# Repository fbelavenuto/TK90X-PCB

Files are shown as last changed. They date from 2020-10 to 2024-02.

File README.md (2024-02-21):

# TK90X-PCB

Recriação da placa de circuito impresso do microcomputador de 8 bits TK90X da Microdigital. Projeto iniciado em setembro de 2020.

## Agradecimentos

Agradecimentos ao Daniel Viana (Danjovic) pelo desenho do esquema no software Eagle, Manoel Carvalho (Neco) pelo encorajamento e scans limpos da PCB e ao grupo [Clube do TK](https://www.facebook.com/groups/clubedotk) do Facebook.

## Revisões

Nesse repositório existem várias revisões relacionadas abaixo, cada revisão contém modificações em relação à revisão anterior.

### Rev. 3

Réplica da placa Rev. 3 da Microdigital (Silk TK90X-B rev 3). Essa versão é para montagem de uma réplica da placa original, sem modificações.

### Rev. 4

As modificações efetuadas são:
- Jumpers de solda para selecionar o tipo de memória DRAM, roteando a alimentação corretamente,
- Jumper de solda para permitir o uso de uma EPROM no lugar da ROM original.

### Rev. 5

As modificações efetuadas são:
- Jumpers de solda nos conectores EAR e MIC para opção de montagem com Jacks P2 mono ou estéreo e saída de áudio no conector MIC
-  Desativação do circuito de RF dando lugar a uma saída de vídeo-composto on-board e conector RCA próprio.

Essa revisão não é encorajada a ser fabricada.

### Rev. 6

As modificações efetuadas são:
- Alteração no IC10 para corrigir a leitura da porta 254, compatibilizando esta porta com o padrão ZX e permitindo a execução de mais softwares.

Alguns componentes não precisam ser montados pela extinção do circuito de RF, veja a documentação específica na pasta *Docs* da revisão.

### Rev. 7

As modificações efetuadas são:
- Alteração nos componentes do circuito de vídeo:
  - Retirados os componentes não necessários referente ao circuito de RF,
  - IC12 foi rotacionado para abrir espaço para um conector RCA extra.
- Adicionado conectores dupont/pinheader:
  - Botão de RESET externo,
  - Chave para seleção de frequência vertical da ULA,
  - LED para uso no gabinete do TK95.
- Jumper de solda para seleção do tipo de sinal de vídeo a ser codificado (NTSC ou PAL/PAL-M) de acordo com o valor de cristal escolhido.
- Jumper de solda para permitir a ligação do sinal necessário para uso da interface [TK-MEM 128K](http://www.luccas.com.br/index.php/8-bits/artigos/23-preparando-o-tk90x-tk95-para-a-tkmem-128).

O conector RCA extra está posicionado no mesmo lugar da saída de RF do ZX Spectrum original, permitindo a montagem da placa dentro do seu gabinete original. Este conector extra é configurado por um jumper de solda que permite mapear o sinal de vídeo ou o sinal de áudio dando a opção de colocar um segundo RCA adaptando o case de um TK90X e ter saída de áudio em RCA.

# Pastas

*Common* possui arquivos referentes a todas as revisões.

Dentro de cada pasta de cada revisão há três subpastas com os nomes *Docs*, *Eagle* e *Gerber*. O esquema elétrico em PDF, imagens, lista de materiais, etc, estão em *Docs*. Na subpasta *Eagle* há os arquivos originais para a versão 9 do software Autodesk Eagle. Para a confecção das placas há os arquivos em formato gerber na pasta *Gerber* que podem ser enviados para uma empresa de fabricação de PCBs.

Para a Rev.7 abra o arquivo [ibom.html](Rev7/Docs/ibom.html) localmente ou acesse [este link](https://fbelavenuto.github.io/pages/TK90X-PCB-Rev7-ibom.html) para visualizar os componentes e seus lugares na placa. Criado com o projeto [InteractiveHtmlBom](https://github.com/openscopeproject/InteractiveHtmlBom), linha de comando: `generate_interactive_bom --highlight-pin1 all --blacklist-empty-val TK90X.brd`

# Observações

É encorajado a fabricação da Rev. 7 por conter mais opções de configuração e correções de problemas conhecidos.

É recomendado a fabricação com finalização ENIG ou ouro no conector Edge para mais durabilidade.

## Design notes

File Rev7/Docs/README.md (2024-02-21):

# Placa TK90X/95 revisão 7

## Lista de materiais

Os componentes estão relacionados [neste](Lista_Material.md) arquivo.

## Instruções de montagem

Algums componentes são opcionais, explicado no texto. A lista de materiais não contempla chaves e botões opcionais relatados no texto.

Para facilitar a montagem abra o arquivo [ibom.html](Rev1/Docs/ibom.html) localmente ou acesse [este link](https://fbelavenuto.github.io/pages/TK90X-PCB-Rev7-ibom.html) para visualizar os componentes e seus lugares na placa. Existe também o arquivo PDF [mapa.pdf](mapa.pdf) para impressão.

Começe soldando os componentes que são montados deitados, como alguns resistores e diodos. Depois solde os componentes que são montados em pé. Deixe os circuitos integrados e conectores para o final.

É possível usar soquetes nos CIs. Para a ULA, caso use a versão clonada em CPLD, utilize soquete torneado para melhor encaixe.

Ao montar a placa, não é necessário soldar nada em `JP`, a PCB já vem com a conexão certa.

Se for utilizar uma EPROM, grave-a com o conteúdo do arquivo [ROM](../../Common/TK90X_ROM_Rev6_7.BIN)

Não esqueça de colocar um dissipador apropriado para o regulador 7805. É possível adaptar uma placa conversora de tensão DC/DC no lugar do 7805.

### Opções de montagem e configuração

No conector de energia `X1` existe o jumper `J1` para configurar o tipo de jack usado. Feche `J1` para jack P2 mono ou deixe aberto para jack P2 estéreo.

Se escolher montar com 32K de RAM alta, montar `IC5`, `IC6`, `IC7`, `IC21`, `IC22`, `IC23`, `IC24`, `IC25`, `IC26`, `IC27` e não montar `D11`, `D12`, `R33`.

Caso escolha somente 16KB de RAM baixa, não montar `IC5`, `IC6`, `IC7`, `IC21`, `IC22`, `IC23`, `IC24`, `IC25`, `IC26`, `IC27` e montar `D11`, `D12`, `R33`.

Nas memórias da RAM baixa, se for utilizar CIs 4116 feche o jumper `J2` para 12V e feche `J3`, se for utilizar CIs 4164 feche o jumper `J2` para 5V e não feche `J3`.

Se for usar a ROM (PROM) original, fechar o jumper `J9` no lado `R`, se for usar EPROM (27C128) fechar jumper no lado `E`.

O jumper `J10` se aberto configura a ULA para trabalhar em 60Hz de sincronismo vertical. Se fechá-lo a ULA é configurada para 50Hz. Pode ser utilizado uma chave externa para esta função.

É possível escolher o padrão de saída de vídeo PAL-M ou NTSC. Para PAL-M utilize um cristal de 14.3044 MHz e feche o jumper `J7` para PAL. NTSC utilize cristal de 14.318MHz e feche `J7` para NTSC.

Na saída e entrada de K7 é possível configurar de acordo com o tipo de conector desejado:
 - No conector do EAR, se utilizar um jack P2 mono, feche o jumper `J5`, se for jack estéreo, feche `J5` somente se for utilizar cabo estéreo. Para jack estéreo e cabo mono não feche `J5`.
 - No conector do MIC utilize um jack estéreo e feche `J4` se quiser saída de áudio no canal esquerdo, ou deixe `J4` aberto para não ter saída de áudio. A saída de som K7 sai pelo canal direito.

A saída de vídeo está ligada no conector RCA `X4`, é possível soldar um conector RCA em `X5` e pelo jumper `J8` escolher que sinal estará presente nesse conector:
 - Se for montar para gabinete ZX não solde `X4`, solde `X5` e configure `J8` para vídeo.
 - Caso queira furar o gabinete do TK90X e ter uma saída de áudio em RCA, solde também `X5` e configure `J8` para áudio.

`X7` é o conector de joystick, solde-o para gabinete TK90X e não o solde para gabinete ZX caso não queira furar o gabinete.

Outra opção de jumper de solda é a conexão para a interface TKMEM. Feche `J6` caso queira ligar o barramento ao circuito responsável por desligar a RAM alta ao conectar a TKMEM.

Caso deseje colocar um push-button externo para RESET, ligue-o ao conector `X8`.

#### Relação de jumpers:

Segue um resumo dos jumpers de solda:

| Nome | Função |
|---|---|
| `JP` | fase de clock |
| `J1` | Jack power mono/estéreo |
| `J2` | Alimentação 12V/5V para as DRAMs |
| `J3` | Alimentação -5V para as DRAMs |
| `J4` | Saída de áudio pelo conector MIC |
| `J5` | Jack EAR mono/estéreo |
| `J6` | Opção TK-MEM |
| `J7` | NTSC/PAL |
| `J8` | Vídeo/áudio em X5 |
| `J9` | ROM/EPROM |
| `J10` | ULA 50/60 Hz |

#### Relação de test points:

Para diagnósticos existem pontos de teste relacionados abaixo:

| Nome | Nome do sinal |
|---|---|
| `TP1` | Clock Z80 |
| `TP2` | Clock ULA |
| `TP3` | Entrada K7 |
| `TP4` | DRAM /RAS |
| `TP5` | DRAM /CAS |
| `TP6` | DRAM /WR |
| `TP7` | Saída Beep ULA |
| `TP8` | Sincronismo composto |
| `TP9` | /ROM select |
| `TP10` | /IRQ |

## Fotos

Segue exemplo de montagem. Foi utilizado soquetes, uma placa DC/DC no lugar do 7805, DRAMs 4416 e EPROM.
 Nesta montagem de validação foram testados todas as opções. Não foi soldado um conector em `X5`, os jacks do MIC e EAR são estéreos e o Jack `X1` é mono. Foi utilizado nos testes uma ULA original e um clone em FPGA, que aparece nas fotos.

Lado dos componentes
*Lado dos componentes*

Lado da solda
*Lado da Solda*

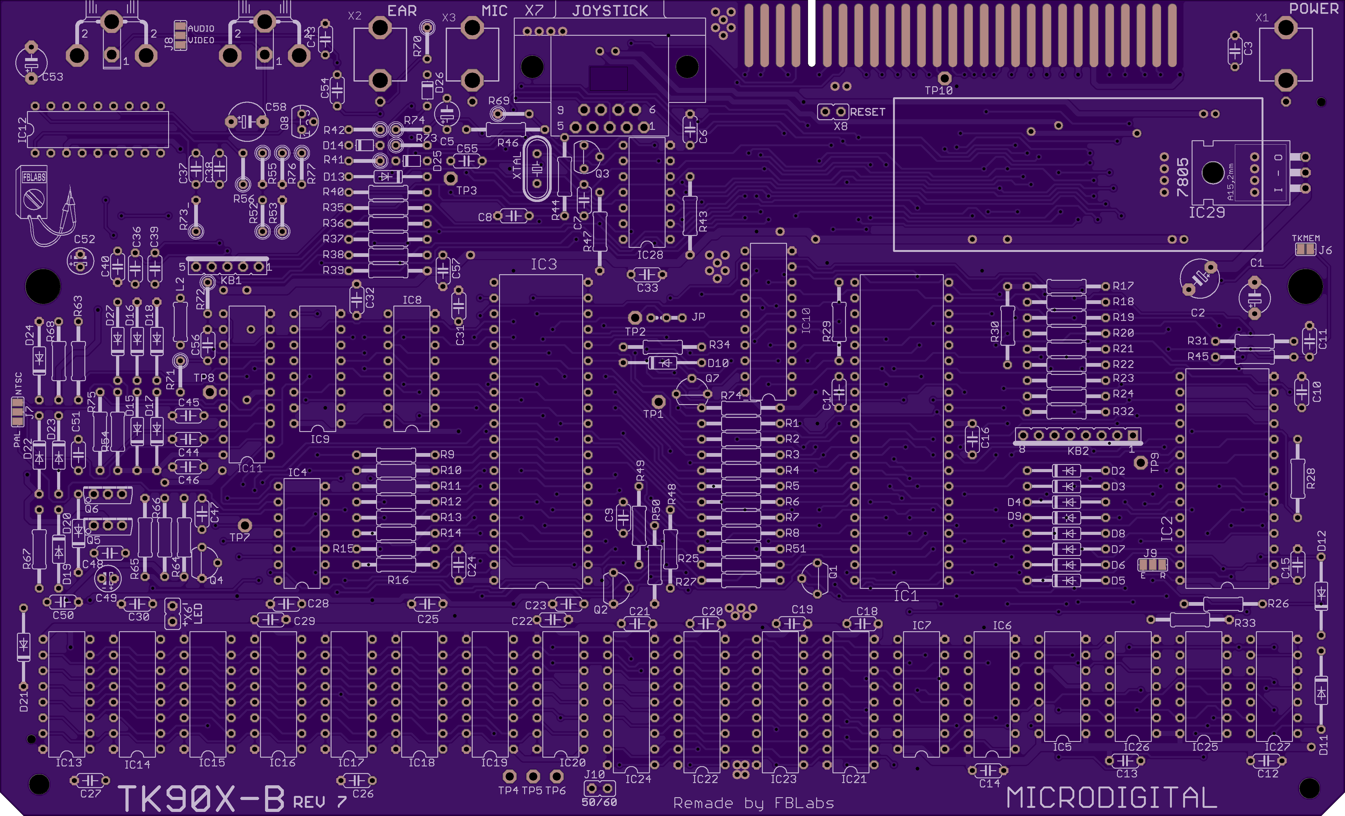
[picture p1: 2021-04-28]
Rev7/Docs/TK90X_PCB_render_top.png

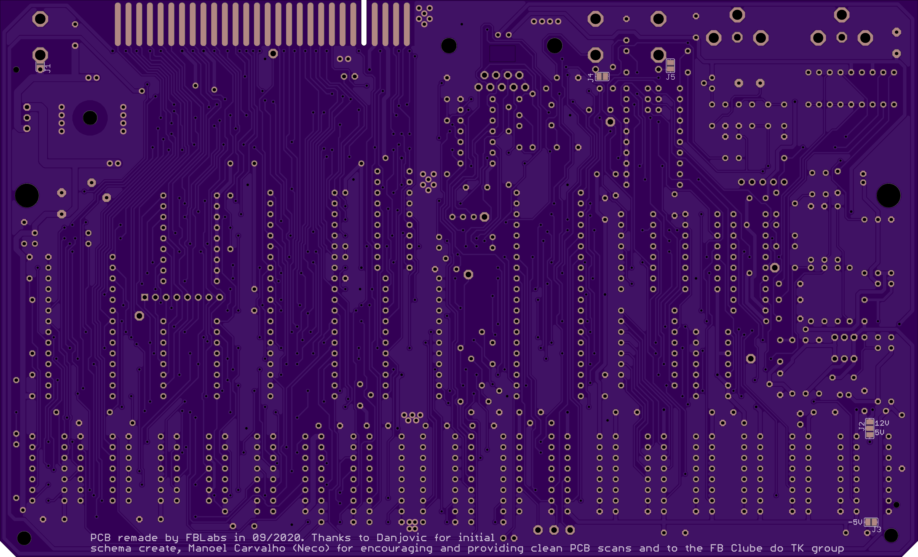
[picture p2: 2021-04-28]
Rev7/Docs/TK90X_PCB_render_bottom.png

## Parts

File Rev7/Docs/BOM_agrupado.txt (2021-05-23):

Qty Value       Device          Package      Parts                                                                                                                                               Description
1   Z80         Z80CPU          DIL40        IC1                                                                                                                                                 Z80 FAMILY DEVICE
1   ROM         25128           DIL28        IC2
1   ULA TK90    ULA-TK90        DIL40        IC3
1   LM1886      LM1886N         DIL20        IC11
1   LM1889      LM1889          DIL18        IC12
8   4116        MK4516          DIL16        IC13, IC14, IC15, IC16, IC17, IC18, IC19, IC20
4   4416        4416            DIL18        IC21, IC22, IC23, IC24                                                                                                                              MEMORY
2   74LS00      74LS00N         DIL14        IC25, IC26                                                                                                                                          Quad 2-input NAND gate
1   74LS04      74LS04N         DIL14        IC28                                                                                                                                                Hex INVERTER
4   74LS157     74S157N         DIL16        IC6, IC7, IC8, IC9                                                                                                                                  Quadruple 2-line to 1-line data SELECTOR/MULTIPLEXER
1   74LS244N    74LS244N        DIL20        IC10                                                                                                                                                Octal BUFFER and LINE DRIVER, 3-state
1   74LS32      74LS32N         DIL14        IC27                                                                                                                                                Quad 2-input OR gate
2   74LS74      74LS74N         DIL14        IC4, IC5                                                                                                                                            Dual D type positive edge triggered FLIP FLOP, preset and clear
1   7805        78XXL           78XXL        IC29                                                                                                                                                VOLTAGE REGULATOR
1   BC517       BC517           TO92         Q8                                                                                                                                                  NPN Darlington Transistor
4   BC548       -NPN-TO92L      TO92L        Q1, Q2, Q4, Q7                                                                                                                                      NPN Transistror
1   BD136       BD140           TO126AV      Q6                                                                                                                                                  PNP TRANSISTOR
1   BD139       BD139           TO126AV      Q5                                                                                                                                                  NPN TRANSISTOR
1   BF494       BF494           TO92-CEB     Q3                                                                                                                                                  NPN TRANSISTOR
21  1N4148      DDO35-12        DO35-12      D2, D3, D4, D5, D6, D7, D8, D9, D10, D11, D12, D13, D15, D16, D17, D18, D19, D20, D22, D23, D27                                                     Diodo
3   1N4148      DIODE-D-5       D-5          D14, D25, D26                                                                                                                                       DIODE
1   5V          DDO35-12        DO35-12      D21                                                                                                                                                 Diodo
1   12V         DDO35-12        DO35-12      D24                                                                                                                                                 Diodo
1   14.3044MHz  CRYSTALHC49S    HC49/S       XTAL                                                                                                                                                CRYSTAL
1   33          R-EU_0207/12    0207/12      R68                                                                                                                                                 RESISTOR, European symbol
1   75          R-EU_0207/5V    0207/5V      R77                                                                                                                                                 RESISTOR, European symbol
1   100         R-EU_0207/12    0207/12      R47                                                                                                                                                 RESISTOR, European symbol
3   100         R-EU_0207/5V    0207/5V      R42, R69, R70                                                                                                                                       RESISTOR, European symbol
1   150         R-EU_0207/5V    0207/5V      R76                                                                                                                                                 RESISTOR, European symbol
2   220         R-EU_0207/12    0207/12      R16, R48                                                                                                                                            RESISTOR, European symbol
23  470         R-EU_0207/12    0207/12      R1, R2, R3, R4, R5, R6, R7, R8, R9, R10, R11, R12, R13, R14, R15, R25, R26, R27, R28, R34, R45, R66, R67                                            RESISTOR, European symbol
1   680         R-EU_0207/5V    0207/5V      R41                                                                                                                                                 RESISTOR, European symbol
4   1K          R-EU_0207/12    0207/12      R33, R49, R50, R65                                                                                                                                  RESISTOR, European symbol
2   1K          R-EU_0207/5V    0207/5V      R55, R56                                                                                                                                            RESISTOR, European symbol
2   2K2         R-EU_0207/12    0207/12      R43, R44                                                                                                                                            RESISTOR, European symbol
1   3K3         R-EU_0207/12    0207/12      R40                                                                                                                                                 RESISTOR, European symbol
2   3K3         R-EU_0207/5V    0207/5V      R71, R73_                                                                                                                                           RESISTOR, European symbol
14  4K7         R-EU_0207/12    0207/12      R30, R31, R32, R35, R36, R37, R38, R39, R49, R51, R54, R63, R64, R74_                                                                               RESISTOR, European symbol
10  10K         R-EU_0207/12    0207/12      R17, R18, R19, R20, R21, R22, R23, R24, R46, R75                                                                                                    RESISTOR, European symbol
5   10K         R-EU_0207/5V    0207/5V      R52, R53, R72, R73, R74                                                                                                                             RESISTOR, European symbol
1   1M          R-EU_0207/12    0207/12      R29                                                                                                                                                 RESISTOR, European symbol
1   33p         C-EU050-024X044 C050-024X044 C7                                                                                                                                                  CAPACITOR, European symbol
4   47p         C-EU050-024X044 C050-024X044 C10, C38, C40, C56                                                                                                                                  CAPACITOR, European symbol
8   100p        C-EU050-024X044 C050-024X044 C6, C8, C9, C11, C44, C45, C46, C47                                                                                                                 CAPACITOR, European symbol
1   1n          C-EU050-024X044 C050-024X044 C57                                                                                                                                                 CAPACITOR, European symbol
1   4n7         C-EU050-024X044 C050-024X044 C39                                                                                                                                                 CAPACITOR, European symbol
1   10n         C-EU050-024X044 C050-024X044 C37                                                                                                                                                 CAPACITOR, European symbol
30  100n        C-EU050-024X044 C050-024X044 C3, C12, C13, C14, C15, C16, C17, C18, C19, C20, C21, C22, C23, C24, C25, C26, C27, C28, C29, C30, C31, C32, C33, C36, C43, C48, C50, C51, C54, C55 CAPACITOR, European symbol
2   1u          CPOL-EUE2-4     E2-4         C49, C52                                                                                                                                            POLARIZED CAPACITOR, European symbol
1   6.3V100u    CPOL-EUE5-4     E5-4         C5                                                                                                                                                  POLARIZED CAPACITOR, European symbol
1   10V1000u    CPOL-EUE5-5     E5-5         C1                                                                                                                                                  POLARIZED CAPACITOR, European symbol
1   16V100u     CPOL-EUE5-5     E5-5         C53                                                                                                                                                 POLARIZED CAPACITOR, European symbol
1   25V100u     CPOL-EUE5-6     E5-6         C2                                                                                                                                                  POLARIZED CAPACITOR, European symbol
1   6.3V220u    CPOL-EUE5-6     E5-6         C58                                                                                                                                                 POLARIZED CAPACITOR, European symbol
1   27u         L-US0207/7      0207/7       L2                                                                                                                                                  INDUCTOR, American symbol
1   JOYSTICK    M09.590S        177-009-MALE X7                                                                                                                                                  SUB-D NorComp 177-009-110-061
1   LED         JP1E            JP1          X6                                                                                                                                                  JUMPER
1   EAR         JACKP2_S        P2S          X2                                                                                                                                                  PJ-301A
1   MIC         JACKP2_S        P2S          X3                                                                                                                                                  PJ-301A
1   POWER       JACKP2_S        P2S          X1                                                                                                                                                  PJ-301A
2   RCA         RCA2PINA1       TOBU3        X4, X5                                                                                                                                              Keystone 589/938 or PDI RCA-061X-Y
1   TECLADO     CON-TECL-5      FE05-1       KB1                                                                                                                                                 TE Connectivity Trio Mate 5-520314-5
1   TECLADO     CON-TECL-8      FE08         KB2                                                                                                                                                 TE Connectivity Trio Mate 5-520315-8

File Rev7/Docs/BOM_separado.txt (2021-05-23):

Part Value       Device          Package      Description
C1   10V1000u    CPOL-EUE5-5     E5-5         POLARIZED CAPACITOR, European symbol
C2   25V100u     CPOL-EUE5-6     E5-6         POLARIZED CAPACITOR, European symbol
C3   100n        C-EU050-024X044 C050-024X044 CAPACITOR, European symbol
C5   6.3V100u    CPOL-EUE5-4     E5-4         POLARIZED CAPACITOR, European symbol
C6   100p        C-EU050-024X044 C050-024X044 CAPACITOR, European symbol
C7   33p         C-EU050-024X044 C050-024X044 CAPACITOR, European symbol
C8   100p        C-EU050-024X044 C050-024X044 CAPACITOR, European symbol
C9   100p        C-EU050-024X044 C050-024X044 CAPACITOR, European symbol
C10  47p         C-EU050-024X044 C050-024X044 CAPACITOR, European symbol
C11  100p        C-EU050-024X044 C050-024X044 CAPACITOR, European symbol
C12  100n        C-EU050-024X044 C050-024X044 CAPACITOR, European symbol
C13  100n        C-EU050-024X044 C050-024X044 CAPACITOR, European symbol
C14  100n        C-EU050-024X044 C050-024X044 CAPACITOR, European symbol
C15  100n        C-EU050-024X044 C050-024X044 CAPACITOR, European symbol
C16  100n        C-EU050-024X044 C050-024X044 CAPACITOR, European symbol
C17  100n        C-EU050-024X044 C050-024X044 CAPACITOR, European symbol
C18  100n        C-EU050-024X044 C050-024X044 CAPACITOR, European symbol
C19  100n        C-EU050-024X044 C050-024X044 CAPACITOR, European symbol
C20  100n        C-EU050-024X044 C050-024X044 CAPACITOR, European symbol
C21  100n        C-EU050-024X044 C050-024X044 CAPACITOR, European symbol
C22  100n        C-EU050-024X044 C050-024X044 CAPACITOR, European symbol
C23  100n        C-EU050-024X044 C050-024X044 CAPACITOR, European symbol
C24  100n        C-EU050-024X044 C050-024X044 CAPACITOR, European symbol
C25  100n        C-EU050-024X044 C050-024X044 CAPACITOR, European symbol
C26  100n        C-EU050-024X044 C050-024X044 CAPACITOR, European symbol
C27  100n        C-EU050-024X044 C050-024X044 CAPACITOR, European symbol
C28  100n        C-EU050-024X044 C050-024X044 CAPACITOR, European symbol
C29  100n        C-EU050-024X044 C050-024X044 CAPACITOR, European symbol
C30  100n        C-EU050-024X044 C050-024X044 CAPACITOR, European symbol
C31  100n        C-EU050-024X044 C050-024X044 CAPACITOR, European symbol
C32  100n        C-EU050-024X044 C050-024X044 CAPACITOR, European symbol
C33  100n        C-EU050-024X044 C050-024X044 CAPACITOR, European symbol
C36  100n        C-EU050-024X044 C050-024X044 CAPACITOR, European symbol
C37  10n         C-EU050-024X044 C050-024X044 CAPACITOR, European symbol
C38  47p         C-EU050-024X044 C050-024X044 CAPACITOR, European symbol
C39  4n7         C-EU050-024X044 C050-024X044 CAPACITOR, European symbol
C40  47p         C-EU050-024X044 C050-024X044 CAPACITOR, European symbol
C43  100n        C-EU050-024X044 C050-024X044 CAPACITOR, European symbol
C44  100p        C-EU050-024X044 C050-024X044 CAPACITOR, European symbol
C45  100p        C-EU050-024X044 C050-024X044 CAPACITOR, European symbol
C46  100p        C-EU050-024X044 C050-024X044 CAPACITOR, European symbol
C47  100p        C-EU050-024X044 C050-024X044 CAPACITOR, European symbol
C48  100n        C-EU050-024X044 C050-024X044 CAPACITOR, European symbol
C49  1u          CPOL-EUE2-4     E2-4         POLARIZED CAPACITOR, European symbol
C50  100n        C-EU050-024X044 C050-024X044 CAPACITOR, European symbol
C51  100n        C-EU050-024X044 C050-024X044 CAPACITOR, European symbol
C52  10u         CPOL-EUE2-4     E2-4         POLARIZED CAPACITOR, European symbol
C53  16V100u     CPOL-EUE5-5     E5-5         POLARIZED CAPACITOR, European symbol
C54  100n        C-EU050-024X044 C050-024X044 CAPACITOR, European symbol
C55  100n        C-EU050-024X044 C050-024X044 CAPACITOR, European symbol
C56  47p         C-EU050-024X044 C050-024X044 CAPACITOR, European symbol
C57  1n          C-EU050-024X044 C050-024X044 CAPACITOR, European symbol
C58  6.3V220u    CPOL-EUE5-6     E5-6         POLARIZED CAPACITOR, European symbol
D2   1N4148      DDO35-12        DO35-12      Diodo
D3   1N4148      DDO35-12        DO35-12      Diodo
D4   1N4148      DDO35-12        DO35-12      Diodo
D5   1N4148      DDO35-12        DO35-12      Diodo
D6   1N4148      DDO35-12        DO35-12      Diodo
D7   1N4148      DDO35-12        DO35-12      Diodo
D8   1N4148      DDO35-12        DO35-12      Diodo
D9   1N4148      DDO35-12        DO35-12      Diodo
D10  1N4148      DDO35-12        DO35-12      Diodo
D11  1N4148      DDO35-12        DO35-12      Diodo
D12  1N4148      DDO35-12        DO35-12      Diodo
D13  1N4148      DDO35-12        DO35-12      Diodo
D14  1N4148      DIODE-D-5       D-5          DIODE
D15  1N4148      DDO35-12        DO35-12      Diodo
D16  1N4148      DDO35-12        DO35-12      Diodo
D17  1N4148      DDO35-12        DO35-12      Diodo
D18  1N4148      DDO35-12        DO35-12      Diodo
D19  1N4148      DDO35-12        DO35-12      Diodo
D20  1N4148      DDO35-12        DO35-12      Diodo
D21  5V          DDO35-12        DO35-12      Diodo
D22  1N4148      DDO35-12        DO35-12      Diodo
D23  1N4148      DDO35-12        DO35-12      Diodo
D24  12V         DDO35-12        DO35-12      Diodo
D25  1N4148      DIODE-D-5       D-5          DIODE
D26  1N4148      DIODE-D-5       D-5          DIODE
D27  1N4148      DDO35-12        DO35-12      Diodo
IC1  Z80         Z80CPU          DIL40        Z80 FAMILY DEVICE
IC2  ROM         25128           DIL28
IC3  ULA TK90    ULA-TK90        DIL40
IC4  74LS74      74LS74N         DIL14        Dual D type positive edge triggered FLIP FLOP, preset and clear
IC5  74LS74      74LS74N         DIL14        Dual D type positive edge triggered FLIP FLOP, preset and clear
IC6  74LS157     74S157N         DIL16        Quadruple 2-line to 1-line data SELECTOR/MULTIPLEXER
IC7  74LS157     74S157N         DIL16        Quadruple 2-line to 1-line data SELECTOR/MULTIPLEXER
IC8  74LS157     74S157N         DIL16        Quadruple 2-line to 1-line data SELECTOR/MULTIPLEXER
IC9  74LS157     74S157N         DIL16        Quadruple 2-line to 1-line data SELECTOR/MULTIPLEXER
IC10 74LS244N    74LS244N        DIL20        Octal BUFFER and LINE DRIVER, 3-state
IC11 LM1886      LM1886N         DIL20
IC12 LM1889      LM1889          DIL18
IC13 4116        MK4516          DIL16
IC14 4116        MK4516          DIL16
IC15 4116        MK4516          DIL16
IC16 4116        MK4516          DIL16
IC17 4116        MK4516          DIL16
IC18 4116        MK4516          DIL16
IC19 4116        MK4516          DIL16
IC20 4116        MK4516          DIL16
IC21 4416        4416            DIL18        MEMORY
IC22 4416        4416            DIL18        MEMORY
IC23 4416        4416            DIL18        MEMORY
IC24 4416        4416            DIL18        MEMORY
IC25 74LS00      74LS00N         DIL14        Quad 2-input NAND gate
IC26 74LS00      74LS00N         DIL14        Quad 2-input NAND gate
IC27 74LS32      74LS32N         DIL14        Quad 2-input OR gate
IC28 74LS04      74LS04N         DIL14        Hex INVERTER
IC29 7805        78XXL           78XXL        VOLTAGE REGULATOR
KB1  TECLADO     CON-TECL-5      FE05-1       FEMALE HEADER
KB2  TECLADO     CON-TECL-8      FE08         FEMALE HEADER
L2   27u         L-US0207/7      0207/7       INDUCTOR, American symbol
Q1   BC548       -NPN-TO92L      TO92L        NPN Transistror
Q2   BC548       -NPN-TO92L      TO92L        NPN Transistror
Q3   BF494       BF494           TO92-CEB     NPN TRANSISTOR
Q4   BC548       -NPN-TO92L      TO92L        NPN Transistror
Q5   BD139       BD139           TO126AV      NPN TRANSISTOR
Q6   BD136       BD140           TO126AV      PNP TRANSISTOR
Q7   BC548       -NPN-TO92L      TO92L        NPN Transistror
Q8   BC517       BC517           TO92         NPN Darlington Transistor
R1   470         R-EU_0207/12    0207/12      RESISTOR, European symbol
R2   470         R-EU_0207/12    0207/12      RESISTOR, European symbol
R3   470         R-EU_0207/12    0207/12      RESISTOR, European symbol
R4   470         R-EU_0207/12    0207/12      RESISTOR, European symbol
R5   470         R-EU_0207/12    0207/12      RESISTOR, European symbol
R6   470         R-EU_0207/12    0207/12      RESISTOR, European symbol
R7   470         R-EU_0207/12    0207/12      RESISTOR, European symbol
R8   470         R-EU_0207/12    0207/12      RESISTOR, European symbol
R9   470         R-EU_0207/12    0207/12      RESISTOR, European symbol
R10  470         R-EU_0207/12    0207/12      RESISTOR, European symbol
R11  470         R-EU_0207/12    0207/12      RESISTOR, European symbol
R12  470         R-EU_0207/12    0207/12      RESISTOR, European symbol
R13  470         R-EU_0207/12    0207/12      RESISTOR, European symbol
R14  470         R-EU_0207/12    0207/12      RESISTOR, European symbol
R15  470         R-EU_0207/12    0207/12      RESISTOR, European symbol
R16  220         R-EU_0207/12    0207/12      RESISTOR, European symbol
R17  10K         R-EU_0207/12    0207/12      RESISTOR, European symbol
R18  10K         R-EU_0207/12    0207/12      RESISTOR, European symbol
R19  10K         R-EU_0207/12    0207/12      RESISTOR, European symbol
R20  10K         R-EU_0207/12    0207/12      RESISTOR, European symbol
R21  10K         R-EU_0207/12    0207/12      RESISTOR, European symbol
R22  10K         R-EU_0207/12    0207/12      RESISTOR, European symbol
R23  10K         R-EU_0207/12    0207/12      RESISTOR, European symbol
R24  10K         R-EU_0207/12    0207/12      RESISTOR, European symbol
R25  470         R-EU_0207/12    0207/12      RESISTOR, European symbol
R26  470         R-EU_0207/12    0207/12      RESISTOR, European symbol
R27  470         R-EU_0207/12    0207/12      RESISTOR, European symbol
R28  470         R-EU_0207/12    0207/12      RESISTOR, European symbol
R29  1M          R-EU_0207/12    0207/12      RESISTOR, European symbol
R30  4K7         R-EU_0207/12    0207/12      RESISTOR, European symbol
R31  4K7         R-EU_0207/12    0207/12      RESISTOR, European symbol
R32  4K7         R-EU_0207/12    0207/12      RESISTOR, European symbol
R33  1K          R-EU_0207/12    0207/12      RESISTOR, European symbol
R34  470         R-EU_0207/12    0207/12      RESISTOR, European symbol
R35  4K7         R-EU_0207/12    0207/12      RESISTOR, European symbol
R36  4K7         R-EU_0207/12    0207/12      RESISTOR, European symbol
R37  4K7         R-EU_0207/12    0207/12      RESISTOR, European symbol
R38  4K7         R-EU_0207/12    0207/12      RESISTOR, European symbol
R39  4K7         R-EU_0207/12    0207/12      RESISTOR, European symbol
R40  3K3         R-EU_0207/12    0207/12      RESISTOR, European symbol
R41  680         R-EU_0207/5V    0207/5V      RESISTOR, European symbol
R42  100         R-EU_0207/5V    0207/5V      RESISTOR, European symbol
R43  2K2         R-EU_0207/12    0207/12      RESISTOR, European symbol
R44  2K2         R-EU_0207/12    0207/12      RESISTOR, European symbol
R45  470         R-EU_0207/12    0207/12      RESISTOR, European symbol
R46  10K         R-EU_0207/12    0207/12      RESISTOR, European symbol
R47  100         R-EU_0207/12    0207/12      RESISTOR, European symbol
R48  220         R-EU_0207/12    0207/12      RESISTOR, European symbol
R49  1K          R-EU_0207/12    0207/12      RESISTOR, European symbol
R50  1K          R-EU_0207/12    0207/12      RESISTOR, European symbol
R51  4K7         R-EU_0207/12    0207/12      RESISTOR, European symbol
R52  10K         R-EU_0207/5V    0207/5V      RESISTOR, European symbol
R53  10K         R-EU_0207/5V    0207/5V      RESISTOR, European symbol
R54  4K7         R-EU_0207/12    0207/12      RESISTOR, European symbol
R55  1K          R-EU_0207/5V    0207/5V      RESISTOR, European symbol
R56  1K          R-EU_0207/5V    0207/5V      RESISTOR, European symbol
R63  4K7         R-EU_0207/12    0207/12      RESISTOR, European symbol
R64  4K7         R-EU_0207/12    0207/12      RESISTOR, European symbol
R65  1K          R-EU_0207/12    0207/12      RESISTOR, European symbol
R66  470         R-EU_0207/12    0207/12      RESISTOR, European symbol
R67  470         R-EU_0207/12    0207/12      RESISTOR, European symbol
R68  33          R-EU_0207/12    0207/12      RESISTOR, European symbol
R69  100         R-EU_0207/5V    0207/5V      RESISTOR, European symbol
R70  100         R-EU_0207/5V    0207/5V      RESISTOR, European symbol
R71  3K3         R-EU_0207/5V    0207/5V      RESISTOR, European symbol
R72  10K         R-EU_0207/5V    0207/5V      RESISTOR, European symbol
R73  10K         R-EU_0207/5V    0207/5V      RESISTOR, European symbol
R73_ 3K3         R-EU_0207/5V    0207/5V      RESISTOR, European symbol
R74  10K         R-EU_0207/5V    0207/5V      RESISTOR, European symbol
R74_ 4K7         R-EU_0207/12    0207/12      RESISTOR, European symbol
R75  10K         R-EU_0207/12    0207/12      RESISTOR, European symbol
R76  150         R-EU_0207/5V    0207/5V      RESISTOR, European symbol
R77  75          R-EU_0207/5V    0207/5V      RESISTOR, European symbol
X1   POWER       JACKP2_S        P2S          PJ-301A
X2   EAR         JACKP2_S        P2S          PJ-301A
X3   MIC         JACKP2_S        P2S          PJ-301A
X4   RCA         RCA2PINA1       TOBU3        Keystone 589/938 or PDI RCA-061X-Y
X5   RCA         RCA2PINA1       TOBU3        Keystone 589/938 or PDI RCA-061X-Y
X6   LED         JP1E            JP1          JUMPER
X7   JOYSTICK    M09.590S        177-009-MALE SUB-D NorComp 177-009-110-061
X8               JP1E            JP1          JUMPER
XTAL 14.3044MHz  CRYSTALHC49S    HC49/S       CRYSTAL

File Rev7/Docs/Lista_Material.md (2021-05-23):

# Lista de material

## Resistores

Todos são resistores de 1/4W

| Qtde | Valor | Obs |
|:----:|---|-----|
| 1 | 33Ω | |
| 1 | 75Ω | |
| 4 | 100Ω  | |
| 1 | 150Ω  | |
| 2 | 220Ω  | |
| 23 | 470Ω  | |
| 1 | 680Ω  | |
| 6 | 1K | 5 un se for montar com 32K |
| 2 | 2K2 | |
| 3 | 3K3 | |
| 14 | 4K7 | |
| 15 | 10K | |
| 1 | 1M | |

## Capacitores

| Qtde | Valor | Tipo |
|:----:|---|---|
|  1 | 33p | Cerâmico |
|  4 | 47p | Cerâmico |
|  8 | 100p  | Cerâmico |
|  1 | 1n | Cerâmico ou Poliester |
|  1 | 4n7 | Cerâmico ou Poliester |
|  1 | 10n | Cerâmico ou Poliester |
|  30  | 100n  | Cerâmico ou Poliester |
|  1 | 1u | Cerâmico ou Eletrolítico |
|  1 | 10u/16V | Eletrolítico |
|  1 | 1000u/16V | Eletrolítico |
|  1 | 100u/6V3  | Eletrolítico |
|  1 | 100u/16V  | Eletrolítico |
|  1 | 100u/25V  | Eletrolítico |
|  1 | 220u/6V3  | Eletrolítico |

## Indutores

| Qtde | Valor | Tamanho |
|:----:|---|---|
| 1 | 27u | 0207/7  |

## Diodos

| Qtde | Valor | Obs |
|:----:|---|-----|
| 24 | 1N4148 | 22 un se for montar com 32K |
| 1 | BZX55C5V1 (ou equivalente) | |
| 1 | BZX55C12 (ou equivalente) ||

## Transistores

| Qtde | Valor |
|:----:|---|
| 1 | BC517 |
| 4 | BC548 |
| 1 | BF494 |
| 1 | BD136 |
| 1 | BD139 |

## Circuitos Integrados

| Qtde | Valor | Obs |
|:----:|---|-----|
| 1 | Z80 | Necessário ser versão NMOS |
| 1 | 27C128 | Gravar conteúdo do arquivo [ROM](../../Common/TK90X_ROM_Rev6_7.BIN) |
| 1 | ULA TK90X | |
| 8 | TMS4116 ou 4464 | |
| 4 | TMS4416 | |
| 2 | 74LS00 | |
| 1 | 74LS04 | |
| 4 | 74LS157 | |
| 1 | 74LS244 | |
| 1 | 74LS32 | |
| 2 | 74LS74 | |
| 1 | LM1886 | |
| 1 | LM1889 | |
| 1 | 7805 | Regulador 7805 com dissipador ou módulo DC/DC |

## Soquetes (opcional)

| Qtde | Tipo |
|:----:|---|
| 2 | 40 pinos |
| 1 | 28 pinos (largo) |
| 2 | 20 pinos |
| 5 | 18 pinos |
| 12 | 16 pinos |
| 6 | 14 pinos |

## Diversos

| Qtde | Valor | Modelo |
|:----:|---|---|
| 1 | Cristal 14.3044MHz ou 14.31818MHz | HC49/S |
| 3 | Jack P2 Mono ou Estéreo | PJ-301A |
| 1 | Conector DE9 | NorComp 177-009-110-061 |
| 1/2 | Conector RCA | AV-8.4-3, Keystone 589/938 ou PDI RCA-061X-Y |
| 1 | Conector Teclado 5 pinos | TE Connectivity Trio Mate 5-520314-5 |
| 1 | Conector Teclado 8 pinos | TE Connectivity Trio Mate 5-520315-8 |
| 3 | Dupont/Pinheader 2 pinos | 2,54mm |

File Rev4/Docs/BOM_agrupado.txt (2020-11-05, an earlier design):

Qty Value          Device          Package      Parts                                                                                                                                                        Description
1                  J2X1MM          03C          JP                                                                                                                                                           Jumper switch 2 x 2.5 mm
2   100            R-EU_0207/12    0207/12      R47, R68                                                                                                                                                     RESISTOR, European symbol
3   100            R-EU_0207/5V    0207/5V      R42, R69, R70                                                                                                                                                RESISTOR, European symbol
32  100n           C-EU050-024X044 C050-024X044 C3, C5, C12, C13, C14, C15, C16, C17, C18, C19, C20, C21, C22, C23, C24, C25, C26, C27, C28, C29, C30, C31, C32, C33, C36, C42, C43, C48, C50, C51, C54, C55 CAPACITOR, European symbol
8   100p           C-EU050-024X044 C050-024X044 C6, C8, C9, C11, C44, C45, C46, C47                                                                                                                          CAPACITOR, European symbol
1   100u           CPOL-EUE5-4     E5-4         C53                                                                                                                                                          POLARIZED CAPACITOR, European symbol
2   100u           CPOL-EUE5-8.5   E5-8,5       C1, C2                                                                                                                                                       POLARIZED CAPACITOR, European symbol
10  10K            R-EU_0207/12    0207/12      R17, R18, R19, R20, R21, R22, R23, R24, R46, R75                                                                                                             RESISTOR, European symbol
3   10K            R-EU_0207/5V    0207/5V      R72, R73, R74                                                                                                                                                RESISTOR, European symbol
1   10n            C-EU050-024X044 C050-024X044 C37                                                                                                                                                          CAPACITOR, European symbol
1   10uH/15K/120pF COIL            COIL         L1                                                                                                                                                           FILTER
1   12V            DDO35-12        DO35-12      D24                                                                                                                                                          Diodo
1   14.3044MHz     CRYSTALHC49S    HC49/S       XTAL                                                                                                                                                         CRYSTAL
4   1K             R-EU_0207/12    0207/12      R33, R49, R50, R65                                                                                                                                           RESISTOR, European symbol
2   1K             R-EU_0207/5V    0207/5V      R55, R56                                                                                                                                                     RESISTOR, European symbol
1   1M             R-EU_0207/12    0207/12      R29                                                                                                                                                          RESISTOR, European symbol
22  1N4148         DDO35-12        DO35-12      D1, D2, D3, D4, D5, D6, D7, D8, D9, D10, D11, D12, D13, D15, D16, D17, D18, D19, D20, D22, D23, D27                                                          Diodo
3   1N4148         DIODE-D-5       D-5          D14, D25, D26                                                                                                                                                DIODE
1   1n             C-EU050-024X044 C050-024X044 C57                                                                                                                                                          CAPACITOR, European symbol
1   1u             CPOL-EUE2-4     E2-4         C49                                                                                                                                                          POLARIZED CAPACITOR, European symbol
1   1u             CPOL-EUE2-5     E2-5         C52                                                                                                                                                          POLARIZED CAPACITOR, European symbol
2   220            R-EU_0207/12    0207/12      R16, R48                                                                                                                                                     RESISTOR, European symbol
2   220            R-EU_0207/5V    0207/5V      R57, R58                                                                                                                                                     RESISTOR, European symbol
1   22K            R-EU_0207/5V    0207/5V      R52                                                                                                                                                          RESISTOR, European symbol
1   27u            L-US0207/7      0207/7       L2                                                                                                                                                           INDUCTOR, American symbol
2   2K2            R-EU_0207/12    0207/12      R43, R44                                                                                                                                                     RESISTOR, European symbol
1   33p            C-EU050-024X044 C050-024X044 C7                                                                                                                                                           CAPACITOR, European symbol
1   39K            R-EU_0207/12    0207/12      R54                                                                                                                                                          RESISTOR, European symbol
2   3K3            R-EU_0207/12    0207/12      R40, R73_                                                                                                                                                    RESISTOR, European symbol
1   3K3            R-EU_0207/5V    0207/5V      R71                                                                                                                                                          RESISTOR, European symbol
8   4116           MK4516          DIL16        IC13, IC14, IC15, IC16, IC17, IC18, IC19, IC20
4   4416           4416            DIL18        IC21, IC22, IC23, IC24                                                                                                                                       MEMORY
24  470            R-EU_0207/12    0207/12      R1, R2, R3, R4, R5, R6, R7, R8, R9, R10, R11, R12, R13, R14, R15, R25, R26, R27, R28, R34, R45, R66, R67, R74_                                               RESISTOR, European symbol
1   470            R-EU_0207/5V    0207/5V      R59                                                                                                                                                          RESISTOR, European symbol
1   47K            R-EU_0207/12    0207/12      R53                                                                                                                                                          RESISTOR, European symbol
5   47p            C-EU050-024X044 C050-024X044 C10, C34, C38, C40, C56                                                                                                                                      CAPACITOR, European symbol
11  4K7            R-EU_0207/12    0207/12      R30, R31, R32, R35, R36, R37, R38, R39, R51, R63, R64                                                                                                        RESISTOR, European symbol
1   4n7            C-EU050-024X044 C050-024X044 C39                                                                                                                                                          CAPACITOR, European symbol
1   5V             DDO35-12        DO35-12      D21                                                                                                                                                          Diodo
1   680            R-EU_0207/5V    0207/5V      R41                                                                                                                                                          RESISTOR, European symbol
2   74LS00         74LS00N         DIL14        IC25, IC26                                                                                                                                                   Quad 2-input NAND gate
1   74LS04         74LS04N         DIL14        IC28                                                                                                                                                         Hex INVERTER
4   74LS157        74S157N         DIL16        IC6, IC7, IC8, IC9                                                                                                                                           Quadruple 2-line to 1-line data SELECTOR/MULTIPLEXER
1   74LS32         74LS32N         DIL14        IC27                                                                                                                                                         Quad 2-input OR gate
1   74LS365N       74LS365N        DIL16        IC10                                                                                                                                                         Hex BUS DRIVER, 3-state
2   74LS74         74LS74N         DIL14        IC4, IC5                                                                                                                                                     Dual D type positive edge triggered FLIP FLOP, preset and clear
1   7805           78XXL           78XXL        7805                                                                                                                                                         VOLTAGE REGULATOR
1   80n            L-EU0204/5      0204/5       L3                                                                                                                                                           INDUCTOR, European symbol
1   82p            C-EU050-024X044 C050-024X044 C41                                                                                                                                                          CAPACITOR, European symbol
1   ?              R-EU_0207/5V    0207/5V      R60                                                                                                                                                          RESISTOR, European symbol
4   BC548          -NPN-TO92L      TO92L        Q1, Q2, Q4, Q7                                                                                                                                               NPN Transistror
1   BD136          BD140           TO126AV      Q6                                                                                                                                                           PNP TRANSISTOR
1   BD139          BD139           TO126AV      Q5                                                                                                                                                           NPN TRANSISTOR
1   BF494          BF494           TO92-CEB     Q3                                                                                                                                                           NPN TRANSISTOR
1   EAR            JACK-MONO       MONO         EAR                                                                                                                                                          FEMALE PRINT CONNECTOR
1   JOYSTICK       M09.590S        177-009-MALE P                                                                                                                                                            SUB-D
1   LM1886         LM1886N         DIL20        IC11
1   LM1889         LM1889          DIL18        IC12
1   MIC            JACK-MONO       MONO         MIC                                                                                                                                                          FEMALE PRINT CONNECTOR
1   POWER          JACK-MONO       MONO         X2                                                                                                                                                           FEMALE PRINT CONNECTOR
1   RF             TPPAD1-13       P1-13        VIDEO(RF)                                                                                                                                                    Test pad
1   ROM            25128           DIL28        IC2
1   TECLADO        CON-TECL-5      FE05-1       KB1                                                                                                                                                          FEMALE HEADER
1   TECLADO        CON-TECL-8      FE08         KB2                                                                                                                                                          FEMALE HEADER
1   ULA TK90       ULA-TK90        DIL40        IC3
1   Varicap        VARICAP-200     D200         D25_
1   Z80            Z80CPU          DIL40        IC1                                                                                                                                                          Z80 FAMILY DEVICE

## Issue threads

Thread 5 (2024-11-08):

Erro no layout rev 7 para NTSC

lrrosa, 2024-11-08:
No J7 ao fazer a seleção NTSC, o R54 deveria polarizar o pino 2 do LM1886 com 12V e não com 5V.
Com isso as cores exibidas na tela não ficam corretas.

Para corrigir, basta deixar o J7 ABERTO, e conectar um resistor de 4k7 entre o pino central do J7 e o K do D24.
* Ver a correção na imagem em anexo.

Agradeço ao Emilio Aoi pela correção.
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

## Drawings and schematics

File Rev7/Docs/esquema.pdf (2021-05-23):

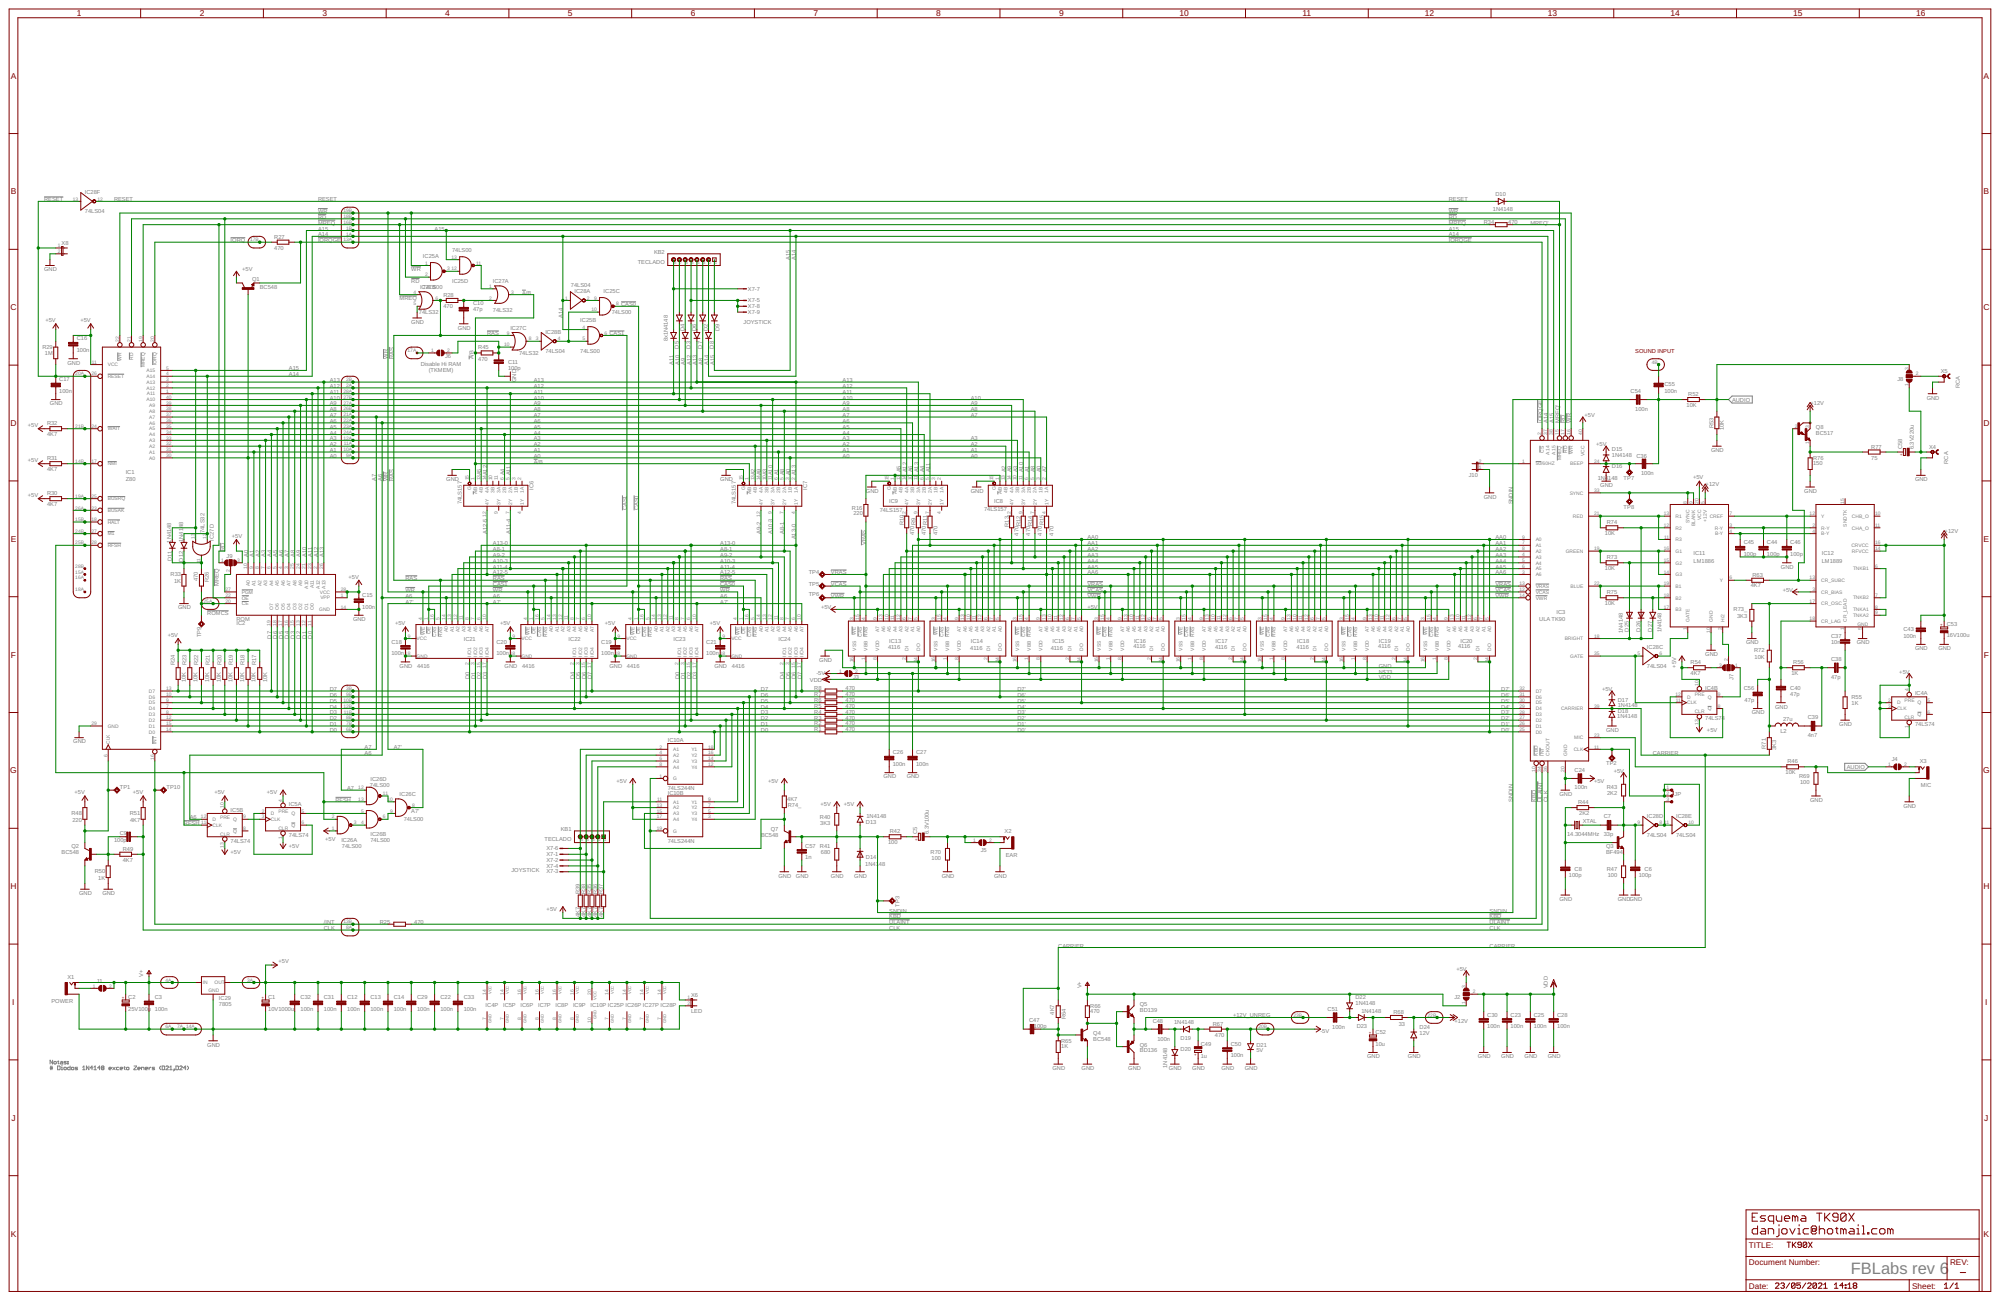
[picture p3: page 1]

RD | 18B
MREQ | 16B

1 2J6 Disable Hi RAM (TKMEM)

21B | 24 | RESET | 3 A14

2 A13 | | | | | 2A | | | A12
1 A12 | | | | | | 28A | | | A11
40 A11 | | | | | | | 27B

38 A9 | 26B | | A8 | | A8
37 A8 | | 21A | | A7 | | A7

31 A2 | | A1 | 10A | | | A1 | | A1 | | A1
30 A1 | | | A0 | 9A | | | A0 | | A0 | | A0

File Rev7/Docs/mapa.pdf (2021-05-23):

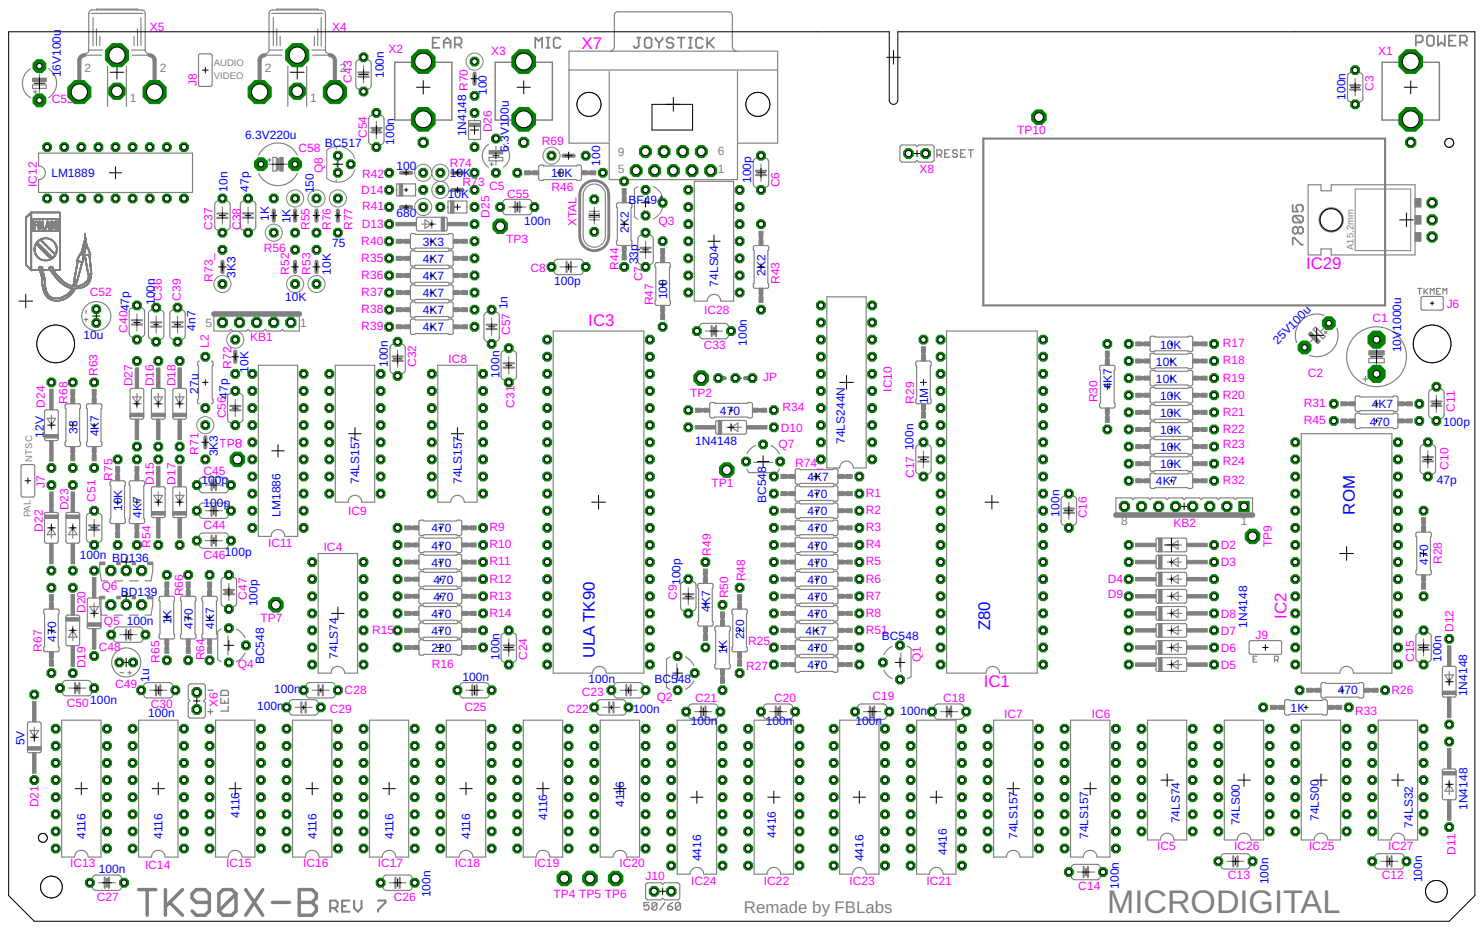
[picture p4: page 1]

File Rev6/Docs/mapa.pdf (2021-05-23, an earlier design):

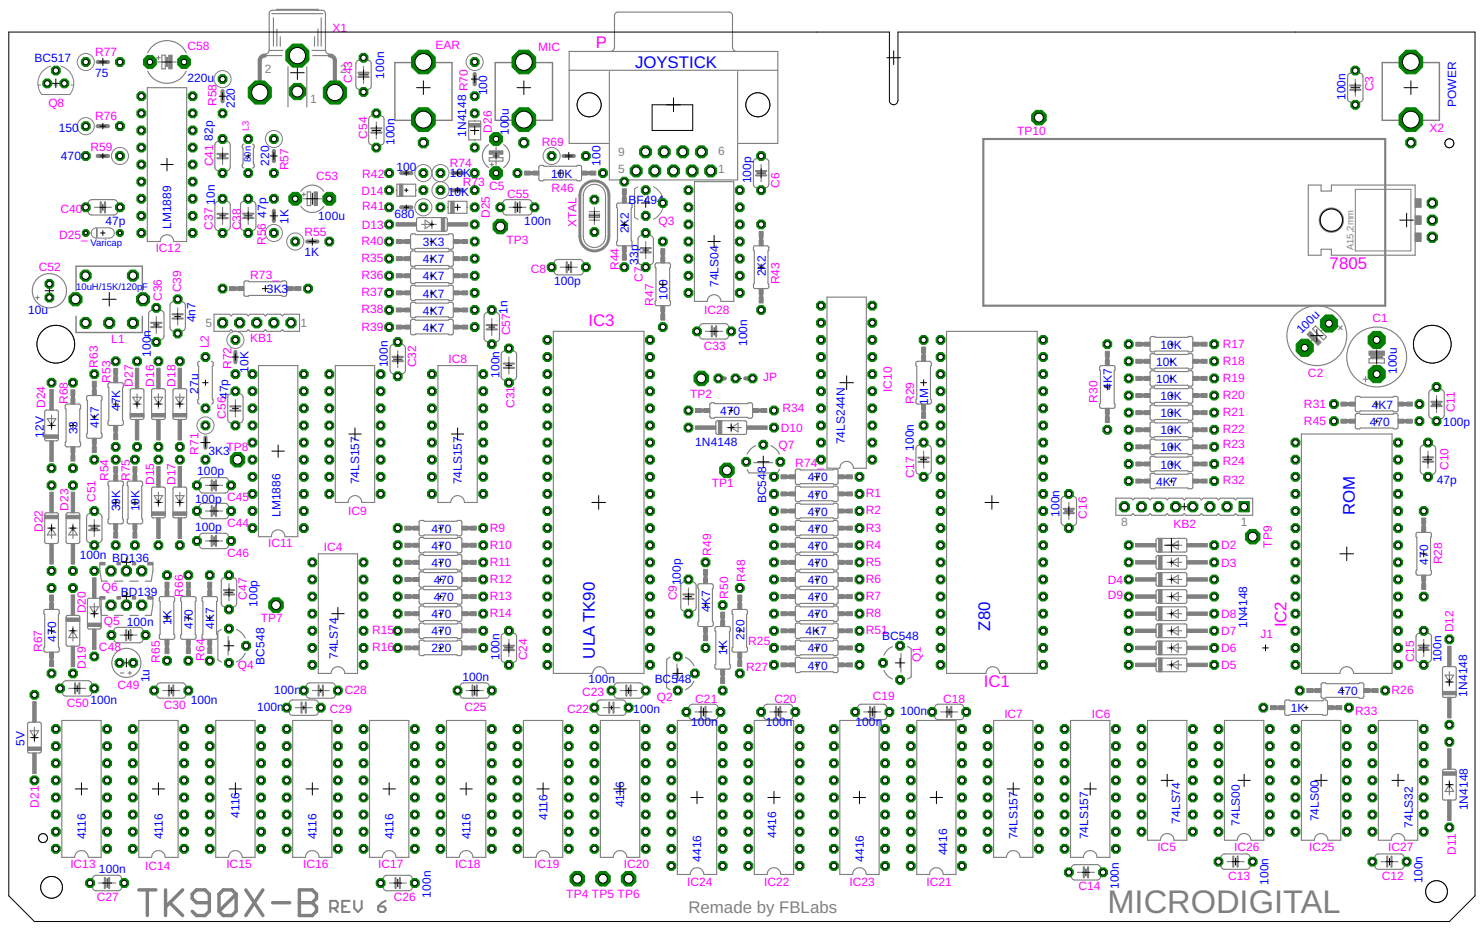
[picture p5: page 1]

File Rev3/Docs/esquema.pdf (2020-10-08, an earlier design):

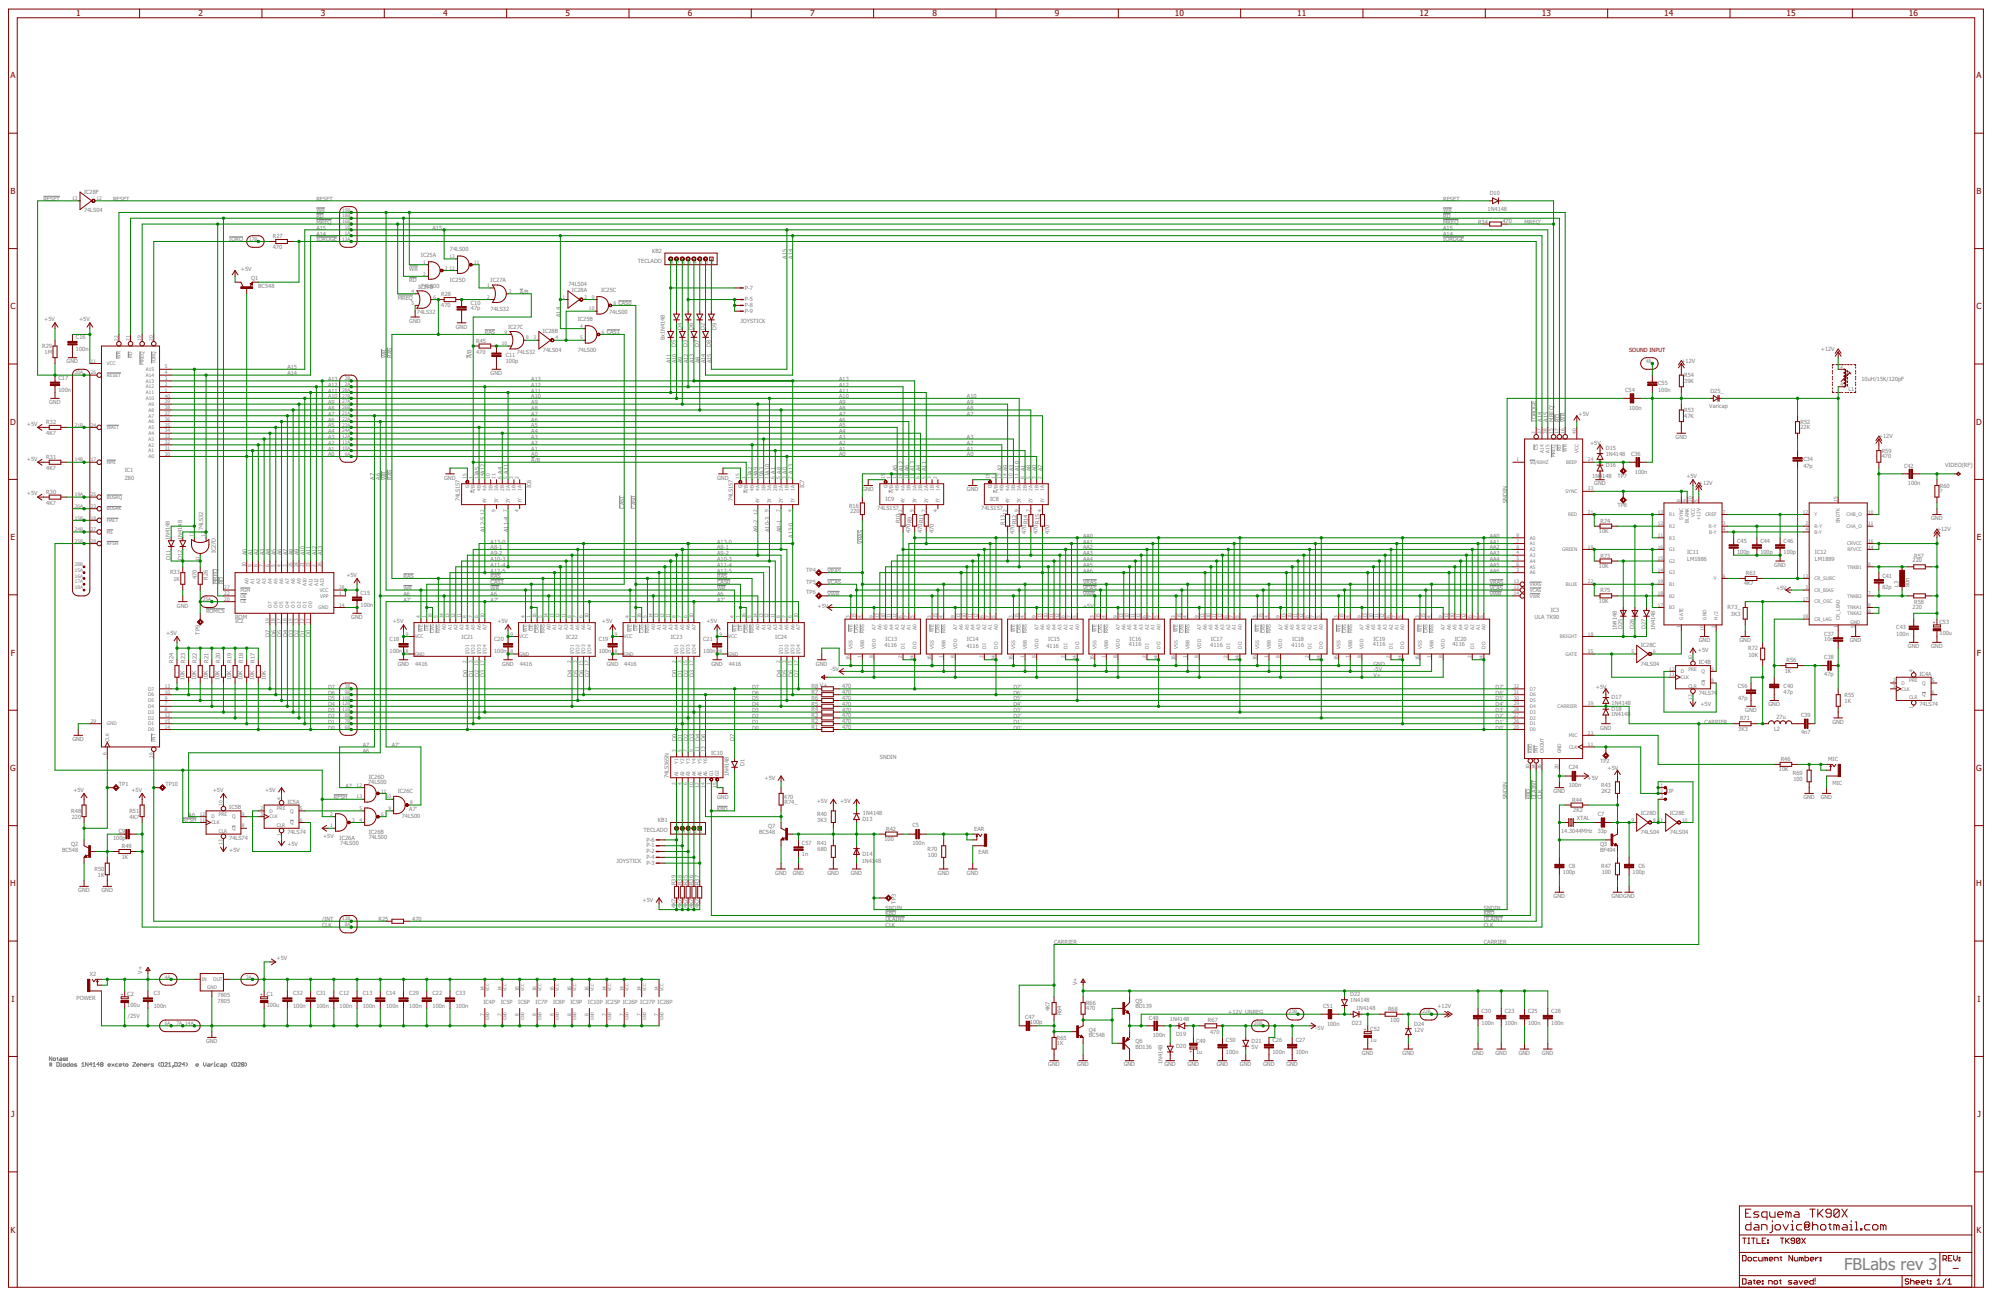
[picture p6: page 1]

RD | 18B
MREQ | 16B

2 A13 | 2A | | | A12 | A12
1 A12 | | 28A | | | | A11
40 A11 | | | 27B

38 A9 | 26B | | | A8 | | A8
37 A8 | A7 | 21A | A7 | | A7 | | A7

31 A2 | 10A | | | A1 | | A1
30 A1 | | 9A | | | A0 | | A0

RFSH 11 | 8

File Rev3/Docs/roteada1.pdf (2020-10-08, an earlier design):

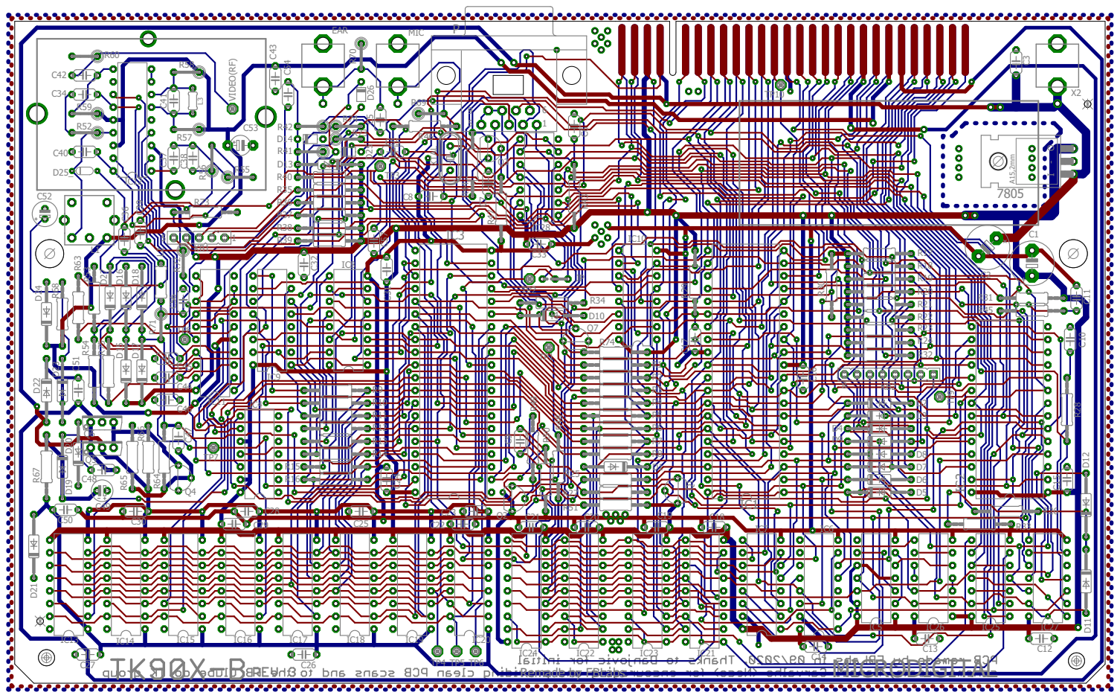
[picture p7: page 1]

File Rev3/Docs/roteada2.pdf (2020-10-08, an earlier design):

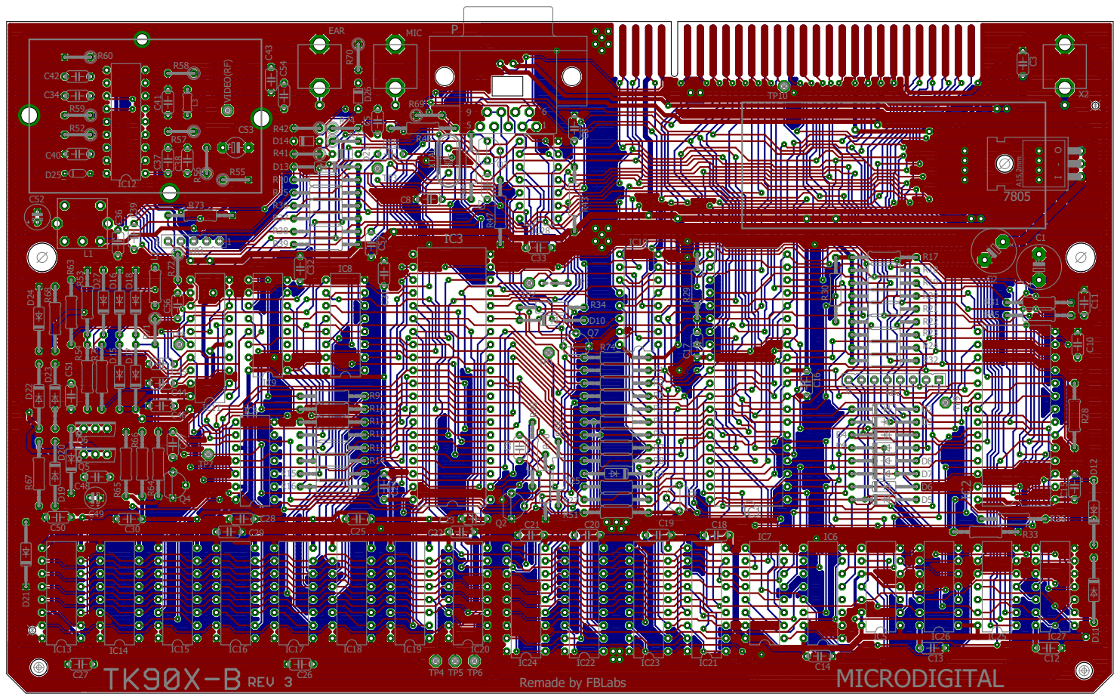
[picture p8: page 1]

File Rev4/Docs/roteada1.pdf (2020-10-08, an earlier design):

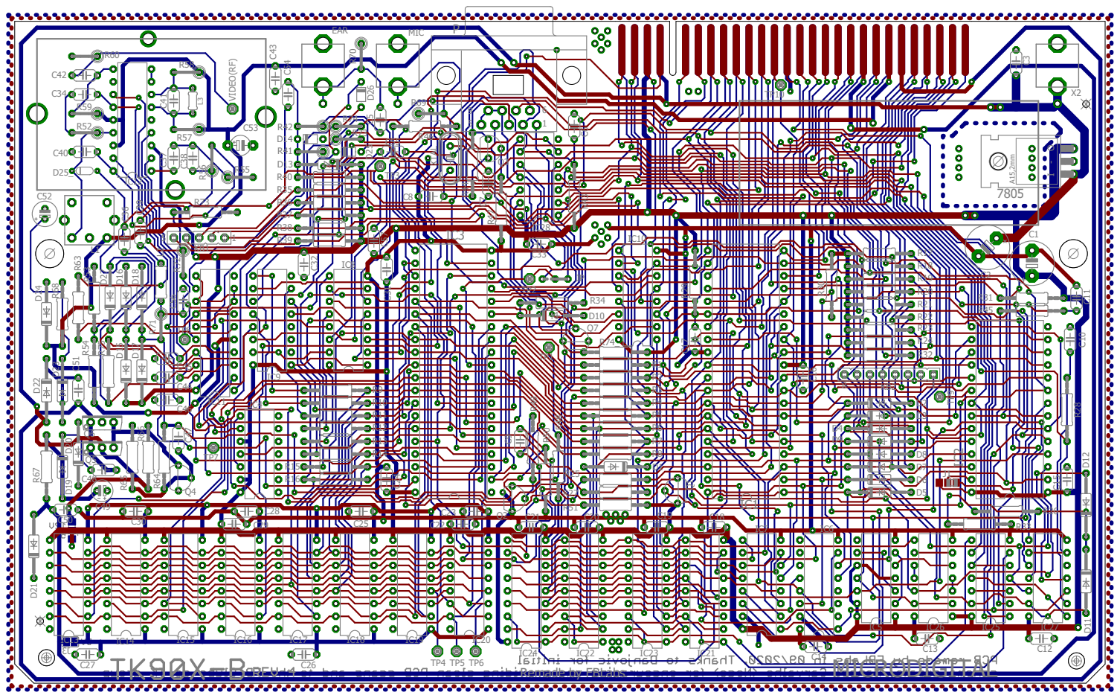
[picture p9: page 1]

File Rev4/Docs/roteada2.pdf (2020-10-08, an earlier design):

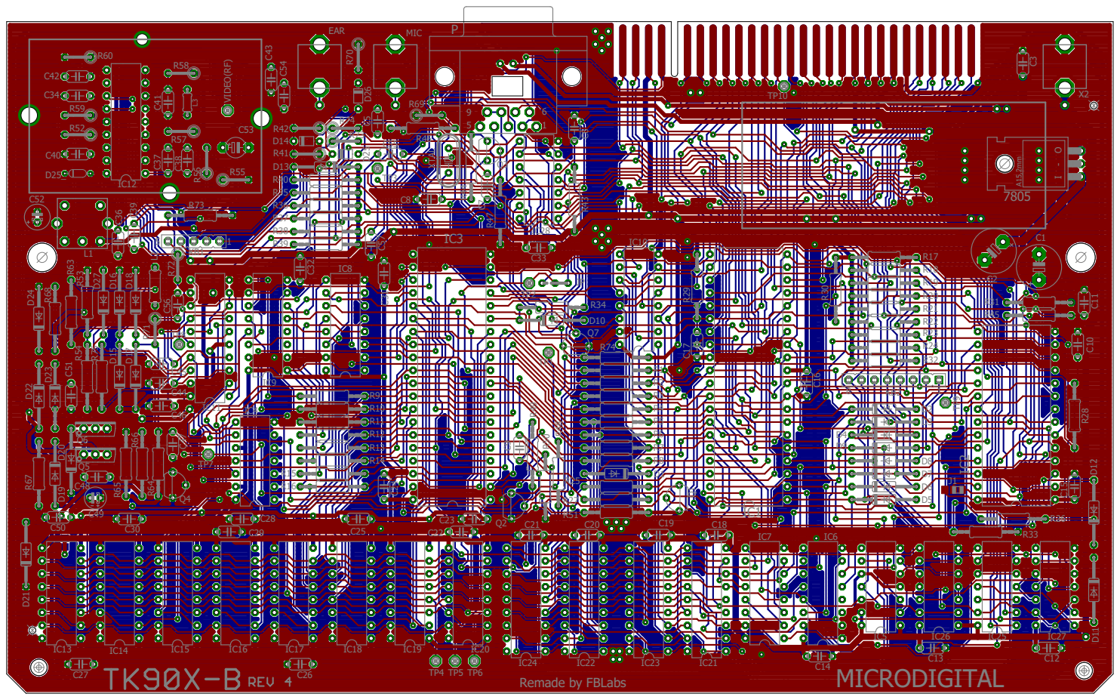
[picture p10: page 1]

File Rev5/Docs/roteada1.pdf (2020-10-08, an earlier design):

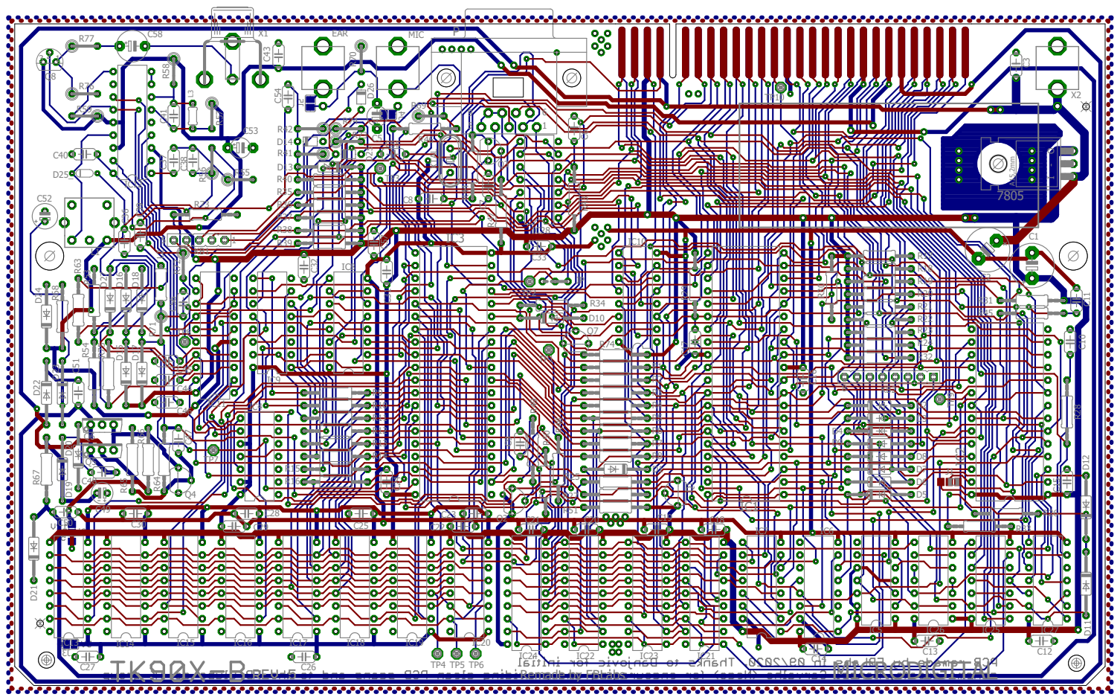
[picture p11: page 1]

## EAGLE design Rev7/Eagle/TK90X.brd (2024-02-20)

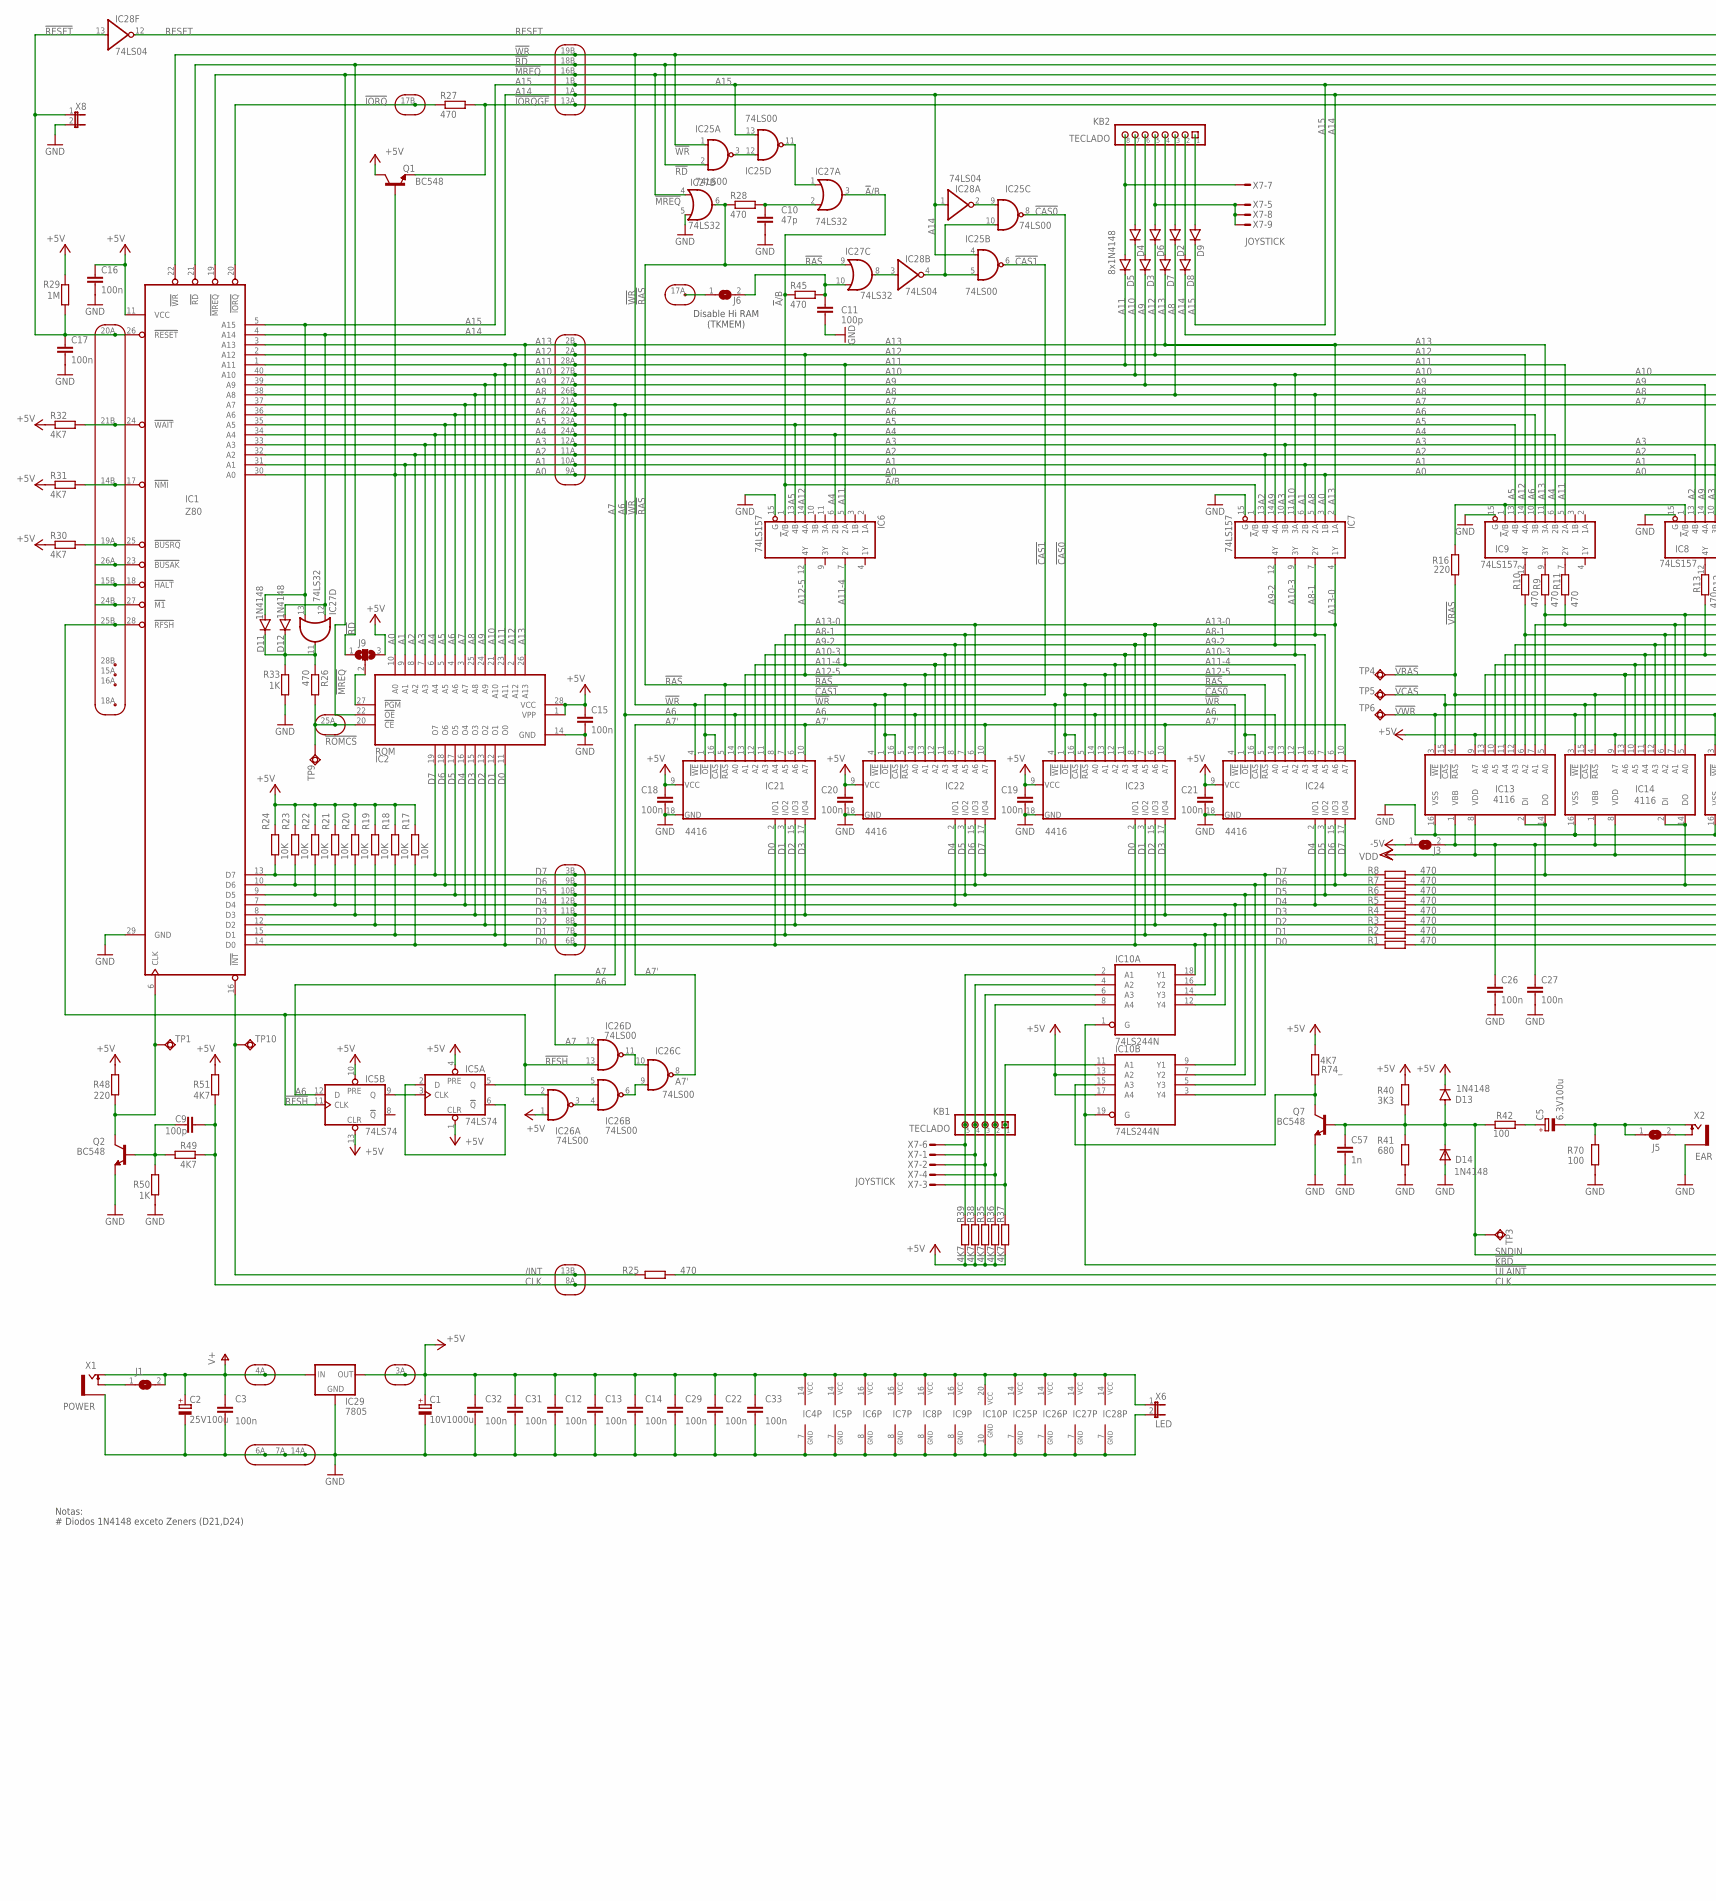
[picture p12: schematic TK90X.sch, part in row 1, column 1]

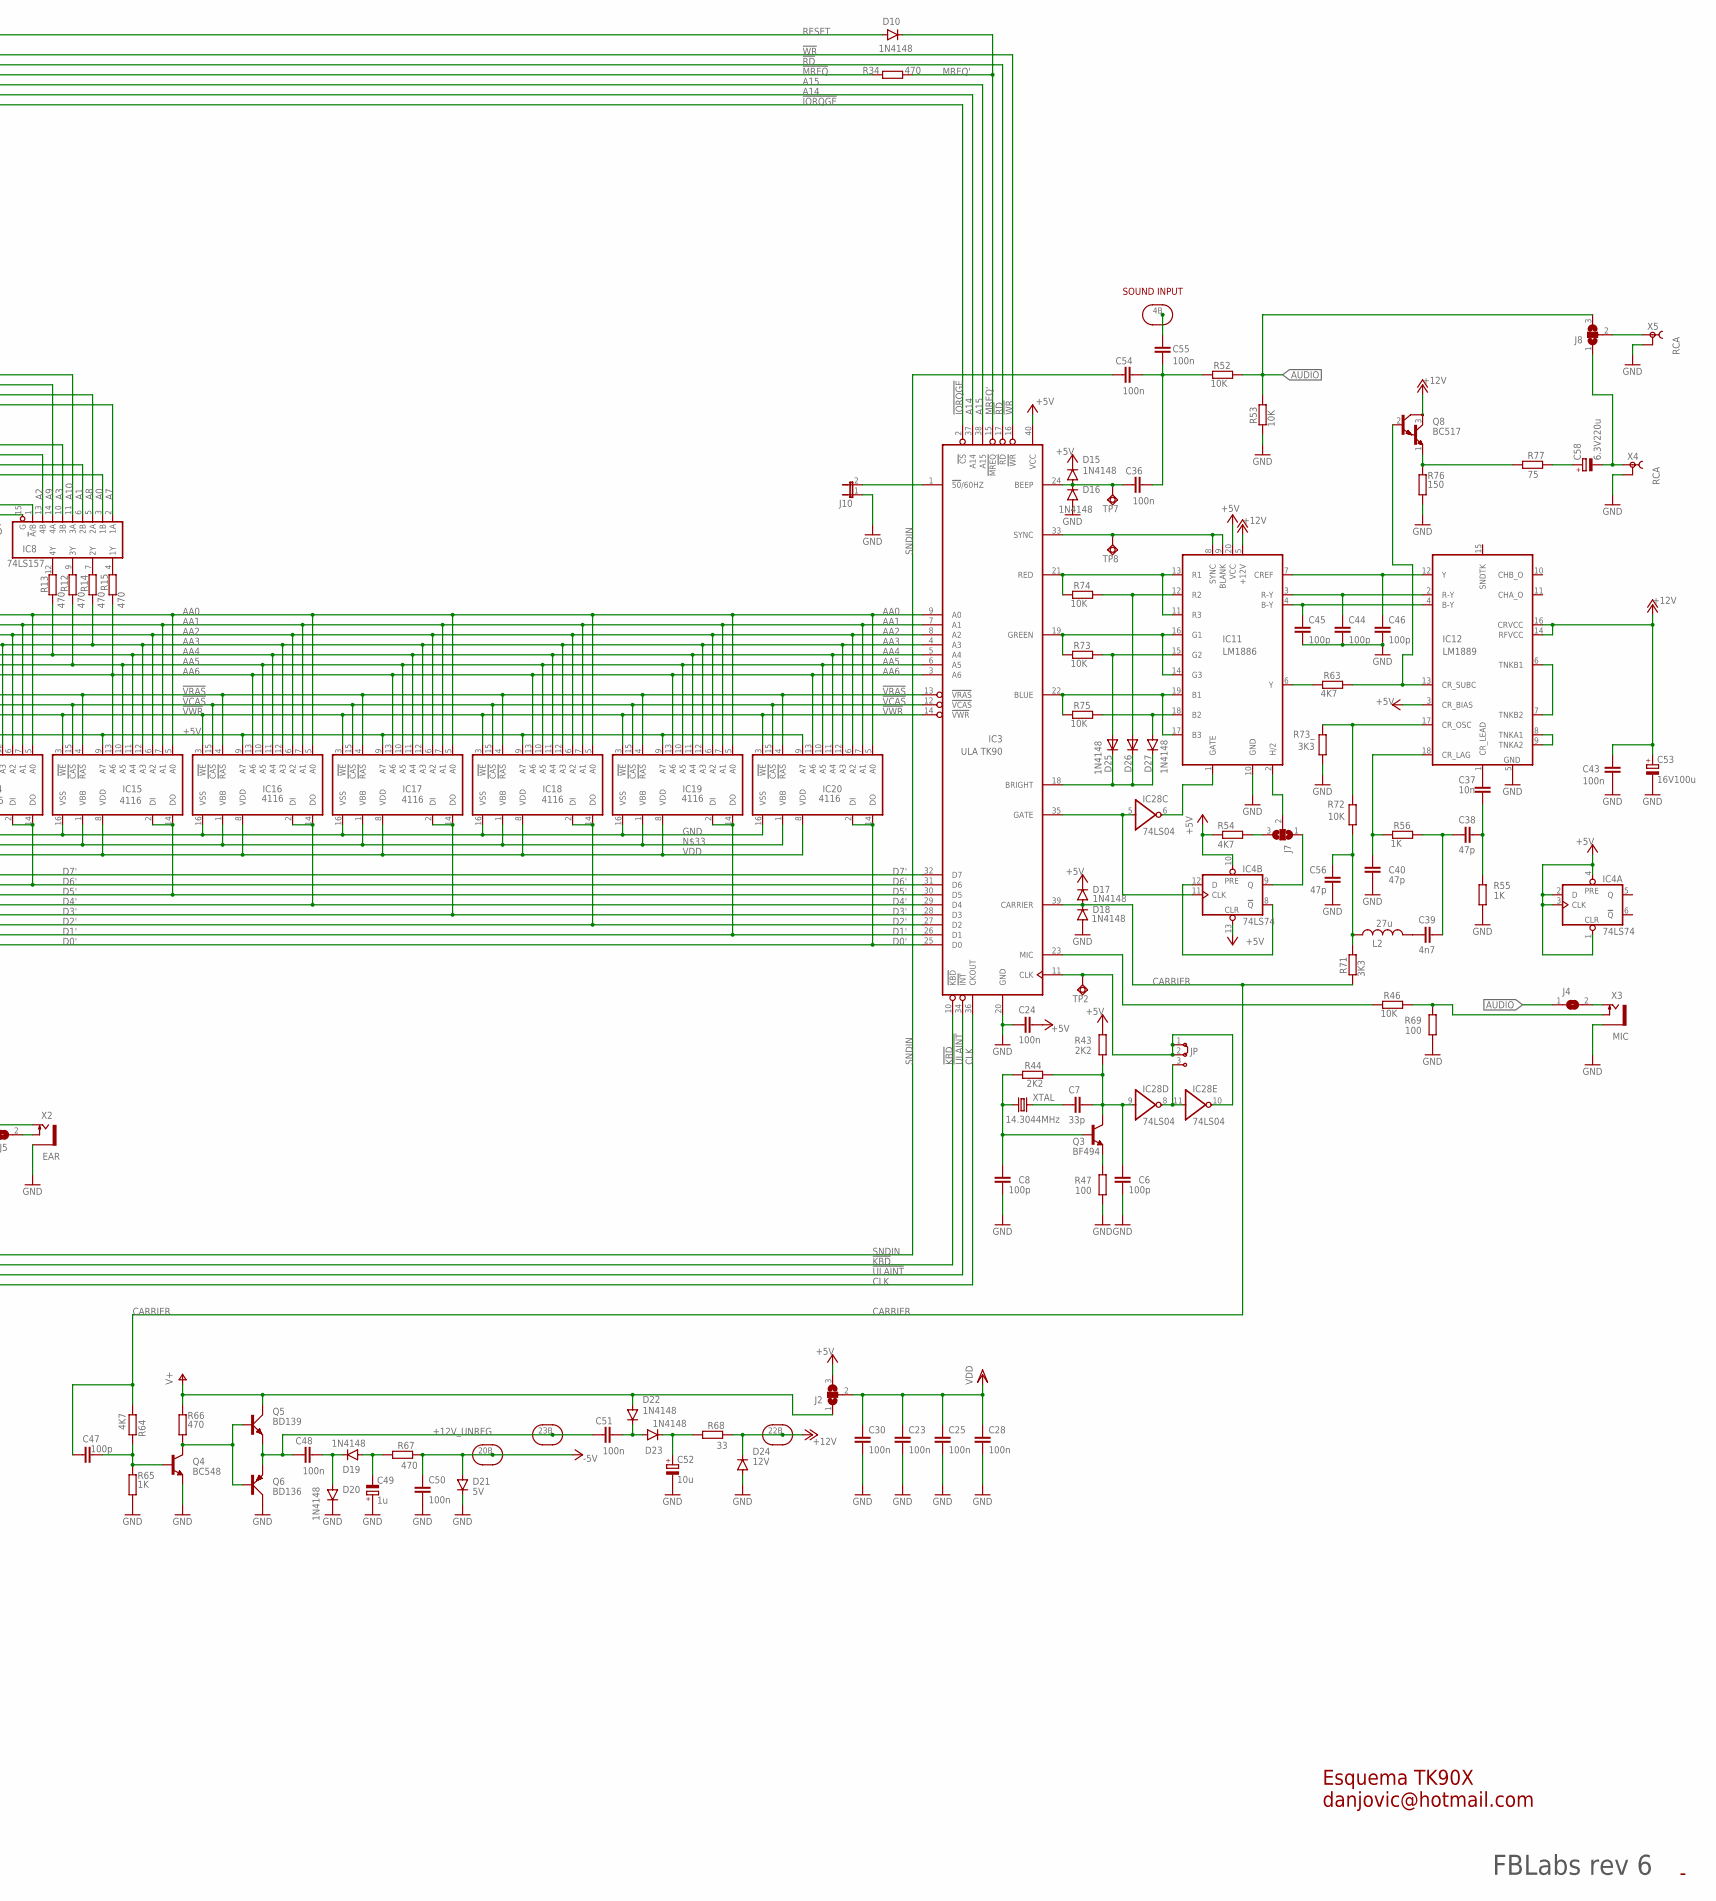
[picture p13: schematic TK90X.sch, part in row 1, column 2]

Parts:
C1: 10V1000u; E5-8,5
C2: 25V100u; E5-6
C3, C12, C13, C14, C15, C16, C17, C18, C19, C20, C21, C22, C23, C24, C25, C26, C27, C28, C29, C30, C31, C32, C33, C36, C43, C48, C50, C51, C54, C55: 100n; C050-024X044
C5: 6.3V100u; E5-4
C6, C8, C9, C11, C44, C45, C46, C47: 100p; C050-024X044
C7: 33p; C050-024X044
C10, C38, C40, C56: 47p; C050-024X044
C37: 10n; C050-024X044
C39: 4n7; C050-024X044
C49: 1u; E2-4
C52: 10u; E2-4
C53: 16V100u; E5-5
C57: 1n; C050-024X044
C58: 6.3V220u; E5-6
D2, D3, D4, D5, D6, D7, D8, D9, D10, D11, D12, D13, D15, D16, D17, D18, D19, D20, D22, D23, D27: 1N4148; DO35-12
D14, D25, D26: 1N4148; D-5
D21: 5V; DO35-12
D24: 12V; DO35-12
IC1: Z80; DIL40
IC2: ROM; DIL28
IC3: ULA TK90; DIL40
IC4, IC5: 74LS74; DIL14
IC6, IC7, IC8, IC9: 74LS157; DIL16
IC10: 74LS244N; DIL20
IC11: LM1886; DIL20
IC12: LM1889; DIL18
IC13, IC14, IC15, IC16, IC17, IC18, IC19, IC20: 4116; DIL16
IC21, IC22, IC23, IC24: 4416; DIL18
IC25, IC26: 74LS00; DIL14
IC27: 74LS32; DIL14
IC28: 74LS04; DIL14
IC29: 7805; 78XXL
J1, J3, J4, J5, J6: SJ
J2, J7, J8, J9: SJ2W; SJ_2
J10: JP1E; JP1
JP: J2X1MM; 03C
KB1: TECLADO; FE05-1
KB2: TECLADO; FE08
L2: 27u; 0207/7
Q1, Q2, Q4, Q7: BC548; TO92L
Q3: BF494; TO92-CEB
Q5: BD139; TO126AV
Q6: BD136; TO126AV
Q8: BC517; TO92
R1, R2, R3, R4, R5, R6, R7, R8, R9, R10, R11, R12, R13, R14, R15, R25, R26, R27, R28, R34, R45, R66, R67: 470; 0207/12
R16, R48: 220; 0207/12
R17, R18, R19, R20, R21, R22, R23, R24, R46, R75: 10K; 0207/12
R29: 1M; 0207/12
R30, R31, R32, R35, R36, R37, R38, R39, R49, R51, R54, R63, R64, R74_: 4K7; 0207/12
R33, R50, R65: 1K; 0207/12
R40: 3K3; 0207/12
R41: 680; 0207/5V
R42, R69, R70: 100; 0207/5V
R43, R44: 2K2; 0207/12
R47: 100; 0207/12
R52, R53, R72, R73, R74: 10K; 0207/5V
R55, R56: 1K; 0207/5V
R68: 33; 0207/12
R71, R73_: 3K3; 0207/5V
R76: 150; 0207/5V
R77: 75; 0207/5V
TP1, TP2, TP3, TP4, TP5, TP6, TP7, TP8, TP9, TP10: TPSQPAD1-13; P1-13
U$1: TK90_EDGE; TK-EDGE
X1: POWER; P2S
X2: EAR; P2S
X3: MIC; P2S
X4, X5: RCA; DX1
X6: LED; JP1
X7: JOYSTICK; 177-009-MALE
X8: JP1E; JP1
XTAL: 14.3044MHz; HC49/S

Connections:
!A!/B: IC6.1 (!A!/B), IC7.1 (!A!/B), IC27.3 (O), R45.1
!BUSAK: IC1.23 (!BUSAK), U$1.26A
!BUSRQ: IC1.25 (!BUSRQ), R30.2, U$1.19A
!CAS0: IC23.1 (!OE), IC23.16 (!CAS), IC24.1 (!OE), IC24.16 (!CAS), IC25.8 (O)
!CAS1: IC21.1 (!OE), IC21.16 (!CAS), IC22.1 (!OE), IC22.16 (!CAS), IC25.6 (O)
!HALT: IC1.18 (!HALT), U$1.15B
!IORQ: IC1.20 (!IORQ), R27.1, U$1.17B
!IORQGE: IC3.2 (!CS), Q1.1 (E), R27.2, U$1.13A
!KBD: IC3.10 (!KBD), IC10.1 (G), IC10.19 (G)
!M1: IC1.27 (!M1), U$1.24B
!MREQ: IC1.19 (!MREQ), IC2.22 (!OE), IC27.4 (I0), R34.1, U$1.16B
!NMI: IC1.17 (!NMI), R31.2, U$1.14B
!RAS: IC21.5 (!RAS), IC22.5 (!RAS), IC23.5 (!RAS), IC24.5 (!RAS), IC27.6 (O), IC27.9 (I0), R28.1
!RD: IC1.21 (!RD), IC3.17 (!RD), IC25.2 (I1), J9.1, U$1.18B
!RESET: C17.1, IC1.26 (!RESET), IC28.13 (I), R29.1, U$1.20A, X8.1
!RFSH: IC1.28 (!RFSH), IC5.11 (CLK), IC26.2 (I1), IC26.13 (I1), U$1.25B
!ROMCS: IC2.20 (!CE), R26.2, TP9.TP, U$1.25A
!ULAINT: IC3.34 (!INT), R25.1
!VCAS: IC3.12 (!VCAS), IC13.15 (!CAS), IC14.15 (!CAS), IC15.15 (!CAS), IC16.15 (!CAS), IC17.15 (!CAS), IC18.15 (!CAS), IC19.15 (!CAS), IC20.15 (!CAS), TP5.TP
!VRAS: IC3.13 (!VRAS), IC13.4 (!RAS), IC14.4 (!RAS), IC15.4 (!RAS), IC16.4 (!RAS), IC17.4 (!RAS), IC18.4 (!RAS), IC19.4 (!RAS), IC20.4 (!RAS), R16.2, TP4.TP
!VWR: IC3.14 (!VWR), IC13.3 (!WE), IC14.3 (!WE), IC15.3 (!WE), IC16.3 (!WE), IC17.3 (!WE), IC18.3 (!WE), IC19.3 (!WE), IC20.3 (!WE), TP6.TP
!WAIT: IC1.24 (!WAIT), R32.2, U$1.21B
!WR: IC1.22 (!WR), IC3.16 (!WR), IC21.4 (!WE), IC22.4 (!WE), IC23.4 (!WE), IC24.4 (!WE), IC25.1 (I0), U$1.19B
+5V: C1.+, C12.2, C13.2, C14.2, C15.1, C16.1, C18.1, C19.1, C20.1, C21.1, C22.2, C24.2, C29.2, C31.2, C32.2, C33.2, D13.C (K), D15.C (K), D17.C (K), IC1.11 (VCC), IC2.1 (VPP), IC2.28 (VCC), IC3.40 (VCC), IC4.1 (CLR), IC4.2 (D), IC4.3 (CLK), IC4.4 (PRE), IC4.10 (PRE), IC4.13 (CLR), IC4.14 (VCC), IC5.1 (CLR), IC5.4 (PRE), IC5.10 (PRE), IC5.13 (CLR), IC5.14 (VCC), IC6.16 (VCC), IC7.16 (VCC), IC8.16 (VCC), IC9.16 (VCC), IC10.13 (A2), IC10.17 (A4), IC10.20 (VCC), IC11.20 (VCC), IC12.3 (CR_BIAS), IC13.9 (A7), IC14.9 (A7), IC15.9 (A7), IC16.9 (A7), IC17.9 (A7), IC18.9 (A7), IC19.9 (A7), IC20.9 (A7), IC21.9 (VCC), IC22.9 (VCC), IC23.9 (VCC), IC24.9 (VCC), IC25.14 (VCC), IC26.1 (I0), IC26.14 (VCC), IC27.14 (VCC), IC28.14 (VCC), IC29.OUT, J2.3, J9.3, Q1.3 (C), R17.2, R18.2, R19.2, R20.2, R21.2, R22.2, R23.2, R24.2, R29.2, R30.1, R31.1, R32.1, R35.1, R36.1, R37.1, R38.1, R39.1, R40.2, R43.2, R48.2, R51.2, R54.1, R74_.2, U$1.3A, X6.1
+12V: C43.2, C53.+, D24.C (K), IC11.5 (+12V), IC12.14 (RFVCC), IC12.16 (CRVCC), Q8.3 (C), R68.1, U$1.22B
+12V_UNREG: C48.1, C51.1, Q5.E, Q6.E, U$1.23B
-5V: C50.1, D21.A, J3.1, R67.1, U$1.20B
/INT: IC1.16 (!INT), R25.2, TP10.TP, U$1.13B
A0: IC1.30 (A0), IC2.10 (A0), IC7.3 (1B), IC8.3 (1B), Q1.2 (B), U$1.9A
A1: IC1.31 (A1), IC2.9 (A1), IC7.6 (2B), IC8.6 (2B), U$1.10A
A2: IC1.32 (A2), IC2.8 (A2), IC7.13 (4B), IC8.13 (4B), U$1.11A
A3: IC1.33 (A3), IC2.7 (A3), IC7.10 (3B), IC8.10 (3B), U$1.12A
A4: IC1.34 (A4), IC2.6 (A4), IC6.6 (2B), IC9.6 (2B), U$1.24A
A5: IC1.35 (A5), IC2.5 (A5), IC6.13 (4B), IC9.13 (4B), U$1.23A
A6: IC1.36 (A6), IC2.4 (A6), IC5.12 (D), IC9.10 (3B), IC21.14 (A0), IC22.14 (A0), IC23.14 (A0), IC24.14 (A0), U$1.22A
A7: IC1.37 (A7), IC2.3 (A7), IC8.2 (1A), IC26.12 (I0), U$1.21A
A7': IC21.10 (A7), IC22.10 (A7), IC23.10 (A7), IC24.10 (A7), IC26.8 (O)
A8: D2.C (K), IC1.38 (A8), IC2.25 (A8), IC7.5 (2A), IC8.5 (2A), U$1.26B
A8-1: IC7.7 (2Y), IC21.7 (A5), IC22.7 (A5), IC23.7 (A5), IC24.7 (A5)
A9: D3.C (K), IC1.39 (A9), IC2.24 (A9), IC7.14 (4A), IC8.14 (4A), U$1.27A
A9-2: IC7.12 (4Y), IC21.8 (A4), IC22.8 (A4), IC23.8 (A4), IC24.8 (A4)
A10: D4.C (K), IC1.40 (A10), IC2.21 (A10), IC7.11 (3A), IC8.11 (3A), U$1.27B
A10-3: IC7.9 (3Y), IC21.11 (A3), IC22.11 (A3), IC23.11 (A3), IC24.11 (A3)
A11: D5.C (K), IC1.1 (A11), IC2.23 (A11), IC6.5 (2A), IC9.5 (2A), U$1.28A
A11-4: IC6.7 (2Y), IC21.12 (A2), IC22.12 (A2), IC23.12 (A2), IC24.12 (A2)
A12: D6.C (K), IC1.2 (A12), IC2.2 (A12), IC6.14 (4A), IC9.14 (4A), U$1.2A
A12-5: IC6.12 (4Y), IC21.13 (A1), IC22.13 (A1), IC23.13 (A1), IC24.13 (A1)
A13: D7.C (K), IC1.3 (A13), IC2.26 (A13), IC7.2 (1A), IC9.11 (3A), U$1.2B
A13-0: IC7.4 (1Y), IC21.6 (A6), IC22.6 (A6), IC23.6 (A6), IC24.6 (A6)
A14: D8.C (K), D12.A, IC1.4 (A14), IC3.37 (A14), IC25.4 (I0), IC27.12 (I0), IC28.1 (I), U$1.1A
A15: D9.C (K), D11.A, IC1.5 (A15), IC3.38 (A15), IC25.13 (I1), IC27.13 (I1), U$1.1B
AA0: IC3.9 (A0), IC13.5 (A0), IC14.5 (A0), IC15.5 (A0), IC16.5 (A0), IC17.5 (A0), IC18.5 (A0), IC19.5 (A0), IC20.5 (A0), R9.1
AA1: IC3.7 (A1), IC13.7 (A1), IC14.7 (A1), IC15.7 (A1), IC16.7 (A1), IC17.7 (A1), IC18.7 (A1), IC19.7 (A1), IC20.7 (A1), R11.1
AA2: IC3.8 (A2), IC13.6 (A2), IC14.6 (A2), IC15.6 (A2), IC16.6 (A2), IC17.6 (A2), IC18.6 (A2), IC19.6 (A2), IC20.6 (A2), R10.1
AA3: IC3.4 (A3), IC13.12 (A3), IC14.12 (A3), IC15.12 (A3), IC16.12 (A3), IC17.12 (A3), IC18.12 (A3), IC19.12 (A3), IC20.12 (A3), R14.1
AA4: IC3.5 (A4), IC13.11 (A4), IC14.11 (A4), IC15.11 (A4), IC16.11 (A4), IC17.11 (A4), IC18.11 (A4), IC19.11 (A4), IC20.11 (A4), R13.1
AA5: IC3.6 (A5), IC13.10 (A5), IC14.10 (A5), IC15.10 (A5), IC16.10 (A5), IC17.10 (A5), IC18.10 (A5), IC19.10 (A5), IC20.10 (A5), R12.1
AA6: IC3.3 (A6), IC13.13 (A6), IC14.13 (A6), IC15.13 (A6), IC16.13 (A6), IC17.13 (A6), IC18.13 (A6), IC19.13 (A6), IC20.13 (A6), R15.1
AUDIO: J4.1, J8.3, R52.1, R53.1
BEEP: C36.1, D15.A, D16.C (K), IC3.24 (BEEP), TP7.TP
CARRIER: C47.1, D17.A, D18.C (K), IC3.39 (CARRIER), R64.2, R71.2
CLK: C9.2, IC3.36 (CKOUT), R49.2, R51.1, U$1.8A
D0: IC1.14 (D0), IC2.11 (O0), IC10.18 (Y1), IC21.2 (I/O1), IC23.2 (I/O1), R1.2, R17.1, U$1.6B
D0': IC3.25 (D0), IC20.2 (DI), IC20.14 (DO), R1.1
D1: IC1.15 (D1), IC2.12 (O1), IC10.16 (Y2), IC21.3 (I/O2), IC23.3 (I/O2), R2.2, R18.1, U$1.7B
D1': IC3.26 (D1), IC19.2 (DI), IC19.14 (DO), R2.1
D2: IC1.12 (D2), IC2.13 (O2), IC10.14 (Y3), IC21.15 (I/O3), IC23.15 (I/O3), R3.2, R19.1, U$1.8B
D2': IC3.27 (D2), IC18.2 (DI), IC18.14 (DO), R3.1
D3: IC1.8 (D3), IC2.15 (O3), IC10.12 (Y4), IC21.17 (I/O4), IC23.17 (I/O4), R4.2, R20.1, U$1.11B
D3': IC3.28 (D3), IC17.2 (DI), IC17.14 (DO), R4.1
D4: IC1.7 (D4), IC2.16 (O4), IC10.9 (Y1), IC22.2 (I/O1), IC24.2 (I/O1), R5.2, R21.1, U$1.12B
D4': IC3.29 (D4), IC16.2 (DI), IC16.14 (DO), R5.1
D5: IC1.9 (D5), IC2.17 (O5), IC10.7 (Y2), IC22.3 (I/O2), IC24.3 (I/O2), R6.2, R22.1, U$1.10B
D5': IC3.30 (D5), IC15.2 (DI), IC15.14 (DO), R6.1
D6: IC1.10 (D6), IC2.18 (O6), IC10.5 (Y3), IC22.15 (I/O3), IC24.15 (I/O3), R7.2, R23.1, U$1.9B
D6': IC3.31 (D6), IC14.2 (DI), IC14.14 (DO), R7.1
D7: IC1.13 (D7), IC2.19 (O7), IC10.3 (Y4), IC22.17 (I/O4), IC24.17 (I/O4), R8.2, R24.1, U$1.3B
D7': IC3.32 (D7), IC13.2 (DI), IC13.14 (DO), R8.1
D19: C48.2, D19.C (K), D20.A
GND: C1.-, C2.-, C3.1, C6.1, C8.1, C10.2, C11.2, C12.1, C13.1, C14.1, C15.2, C16.2, C17.2, C18.2, C19.2, C20.2, C21.2, C22.1, C23.2, C24.1, C25.2, C26.2, C27.2, C28.2, C29.1, C30.2, C31.1, C32.1, C33.1, C40.1, C43.1, C44.2, C45.2, C46.2, C49.+, C50.2, C52.-, C53.-, C56.1, C57.2, D14.A, D16.A, D18.A, D20.C (K), D21.C (K), D24.A, IC1.29 (GND), IC2.14 (GND), IC3.20 (GND), IC4.7 (GND), IC5.7 (GND), IC6.8 (GND), IC6.15 (G), IC7.8 (GND), IC7.15 (G), IC8.8 (GND), IC8.15 (G), IC9.8 (GND), IC9.15 (G), IC10.10 (GND), IC11.10 (GND), IC12.5 (GND), IC13.16 (VSS), IC14.16 (VSS), IC15.16 (VSS), IC16.16 (VSS), IC17.16 (VSS), IC18.16 (VSS), IC19.16 (VSS), IC20.16 (VSS), IC21.18 (GND), IC22.18 (GND), IC23.18 (GND), IC24.18 (GND), IC25.7 (GND), IC26.7 (GND), IC27.5 (I1), IC27.7 (GND), IC28.7 (GND), IC29.GND, J10.1, Q2.1 (E), Q4.1 (E), Q6.C, Q7.1 (E), R33.2, R41.1, R47.1, R50.1, R53.2, R55.2, R65.2, R69.1, R70.1, R73_.2, R76.2, U$1.6A, U$1.7A, U$1.14A, X1.SLEEVE, X2.SLEEVE, X3.SLEEVE, X4.2, X4.2@1 (2), X4.2@2 (2), X5.2, X5.2@1 (2), X5.2@2 (2), X6.2, X8.2
MREQ': D10.C (K), IC3.15 (!MREQ), R34.2
unnamed: IC5.3 (CLK), IC5.9 (Q)
unnamed: IC5.2 (D), IC5.6 (!Q)
unnamed: IC5.5 (Q), IC26.5 (I1)
unnamed: IC26.3 (O), IC26.4 (I0)
unnamed: IC26.10 (I1), IC26.11 (O)
unnamed: IC26.6 (O), IC26.9 (I0)
unnamed: IC25.3 (O), IC25.12 (I0)
unnamed: IC10.2 (A1), KB1.5, R39.2, X7.6
unnamed: C5.+, R42.1
unnamed: D11.C (K), D12.C (K), IC27.11 (O), R26.1, R33.1
unnamed: C10.1, IC27.2 (I1), R28.2
unnamed: C11.1, IC27.10 (I1), J6.2, R45.2
unnamed: IC25.5 (I1), IC25.10 (I1), IC28.4 (O)
unnamed: IC25.11 (O), IC27.1 (I0)
unnamed: IC27.8 (O), IC28.3 (I)
unnamed: C5.-, J5.1, R70.2, X2.TIP
unnamed: IC9.9 (3Y), R9.2
unnamed: C7.1, XTAL.2
unnamed: IC9.12 (4Y), R10.2
unnamed: IC9.7 (2Y), R11.2
unnamed: IC8.9 (3Y), R12.2
unnamed: IC8.12 (4Y), R13.2
unnamed: IC25.9 (I0), IC28.2 (O)
unnamed: IC10.4 (A2), KB1.4, R38.2, X7.1
unnamed: IC10.6 (A3), KB1.3, R35.2, X7.2
unnamed: C9.1, Q2.2 (B), R49.1, R50.2
unnamed: IC10.8 (A4), KB1.2, R36.2, X7.4
unnamed: IC10.11 (A1), KB1.1, R37.2, X7.3
unnamed: IC10.15 (A3), Q7.3 (C), R74_.1
unnamed: IC8.7 (2Y), R14.2
unnamed: IC8.4 (1Y), R15.2
unnamed: IC8.1 (!A!/B), IC9.1 (!A!/B), R16.1
unnamed: C26.1, C27.1, IC13.1 (VBB), IC14.1 (VBB), IC15.1 (VBB), IC16.1 (VBB), IC17.1 (VBB), IC18.1 (VBB), IC19.1 (VBB), IC20.1 (VBB), J3.2
unnamed: D5.A, KB2.8, X7.7
unnamed: D4.A, KB2.7
unnamed: D3.A, KB2.6
unnamed: Q3.E, R47.2
unnamed: D7.A, KB2.4
unnamed: D2.A, KB2.3
unnamed: D8.A, KB2.2
unnamed: D9.A, KB2.1
unnamed: D6.A, KB2.5, X7.5, X7.8, X7.9
unnamed: C51.2, D22.C (K), D23.A
unnamed: R46.1, R69.2, X3.RING
unnamed: C6.2, C7.2, IC28.9 (I), Q3.C, R43.1, R44.1
unnamed: IC28.8 (O), IC28.11 (I), JP.3
unnamed: IC3.11 (CLK), IC28.10 (O), JP.1, JP.2, TP2.TP
unnamed: Q8.1 (E), R76.1, R77.1
unnamed: IC3.23 (MIC), R46.2
unnamed: J4.2, X3.TIP
unnamed: C47.2, Q4.2 (B), R64.1, R65.1
unnamed: C55.2, U$1.4B
unnamed: Q4.3 (C), Q5.B, Q6.B, R66.2
unnamed: IC3.33 (SYNC), IC11.8 (SYNC), IC11.9 (BLANK), TP8.TP
unnamed: IC3.21 (RED), IC11.11 (R3), IC11.13 (R1), R74.2
unnamed: C49.-, D19.A, R67.2
unnamed: C52.+, D23.C (K), R68.2
unnamed: IC3.19 (GREEN), IC11.14 (G3), IC11.16 (G1), R73.2
unnamed: IC3.35 (GATE), IC4.11 (CLK), IC28.5 (I)
unnamed: IC3.22 (BLUE), IC11.17 (B3), IC11.19 (B1), R75.2
unnamed: D25.A, IC11.15 (G2), R73.1
unnamed: D26.A, IC11.12 (R2), R74.1
unnamed: D27.A, IC11.18 (B2), R75.1
unnamed: D25.C, D26.C, D27.C (K), IC3.18 (BRIGHT)
unnamed: IC4.8 (!Q), IC4.12 (D)
unnamed: IC11.6 (Y), R63.2
unnamed: IC11.1 (GATE), IC28.6 (O)
unnamed: IC11.2 (H/2), J7.2
unnamed: IC12.13 (CR_SUBC), Q8.2 (B), R63.1
unnamed: C46.1, IC11.7 (CREF), IC12.12 (Y)
unnamed: C44.1, IC11.3 (R-Y), IC12.2 (R-Y)
unnamed: C45.1, IC11.4 (B-Y), IC12.4 (B-Y)
unnamed: IC4.9 (Q), J7.1
unnamed: J8.2, X5.1
unnamed: IC12.6 (TNKB1), IC12.7 (TNKB2)
unnamed: C58.+, R77.2
unnamed: IC12.17 (CR_OSC), R72.1, R73_.1
unnamed: C40.2, IC12.18 (CR_LAG), R56.2
unnamed: C56.2, L2.1, R71.1, R72.2
unnamed: C37.2, IC12.1 (CR_LEAD)
unnamed: C38.1, C39.2, R56.1
unnamed: C37.1, C38.2, R55.1
unnamed: C39.1, L2.2
unnamed: IC2.27 (!PGM), J9.2
unnamed: IC12.8 (TNKA1), IC12.9 (TNKA2)
unnamed: J1.1, X1.RING
unnamed: IC3.1 (!50!/60HZ), J10.2
unnamed: J5.2, X2.RING
unnamed: J6.1, U$1.17A
unnamed: J7.3, R54.2
unnamed: C36.2, C54.2, C55.1, R52.2
Q3: C8.2, Q3.B, R44.2, XTAL.1
RESET: D10.A, IC28.12 (O)
SNDIN: C54.1, C57.1, D13.A, D14.C, Q7.2 (B), R40.1, R41.2, R42.2, TP3.TP
V+: C2.+, C3.2, D22.A, IC29.IN, J1.2, J2.1, Q5.C, R66.1, U$1.4A, X1.TIP
VDD: C23.1, C25.1, C28.1, C30.1, IC13.8 (VDD), IC14.8 (VDD), IC15.8 (VDD), IC16.8 (VDD), IC17.8 (VDD), IC18.8 (VDD), IC19.8 (VDD), IC20.8 (VDD), J2.2
VIDEO: C58.-, J8.1, X4.1
Z80CLK: IC1.6 (CLK), Q2.3 (C), R48.1, TP1.TP

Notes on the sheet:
JOYSTICK
Esquema TK90X
danjovic@hotmail.com
SOUND INPUT
Notas:
# Diodos 1N4148 exceto Zeners (D21,D24)
8x1N4148
FBLabs rev 6
Disable Hi RAM (TKMEM)

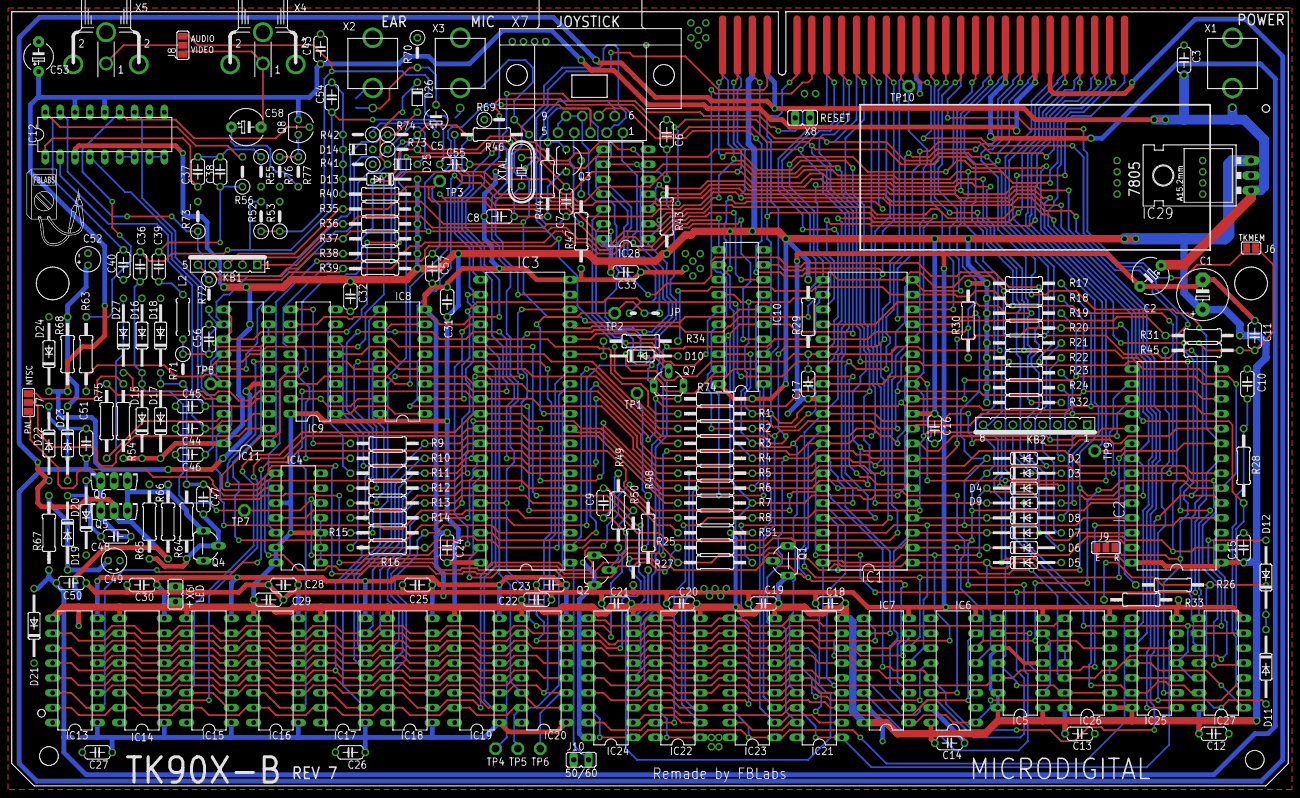
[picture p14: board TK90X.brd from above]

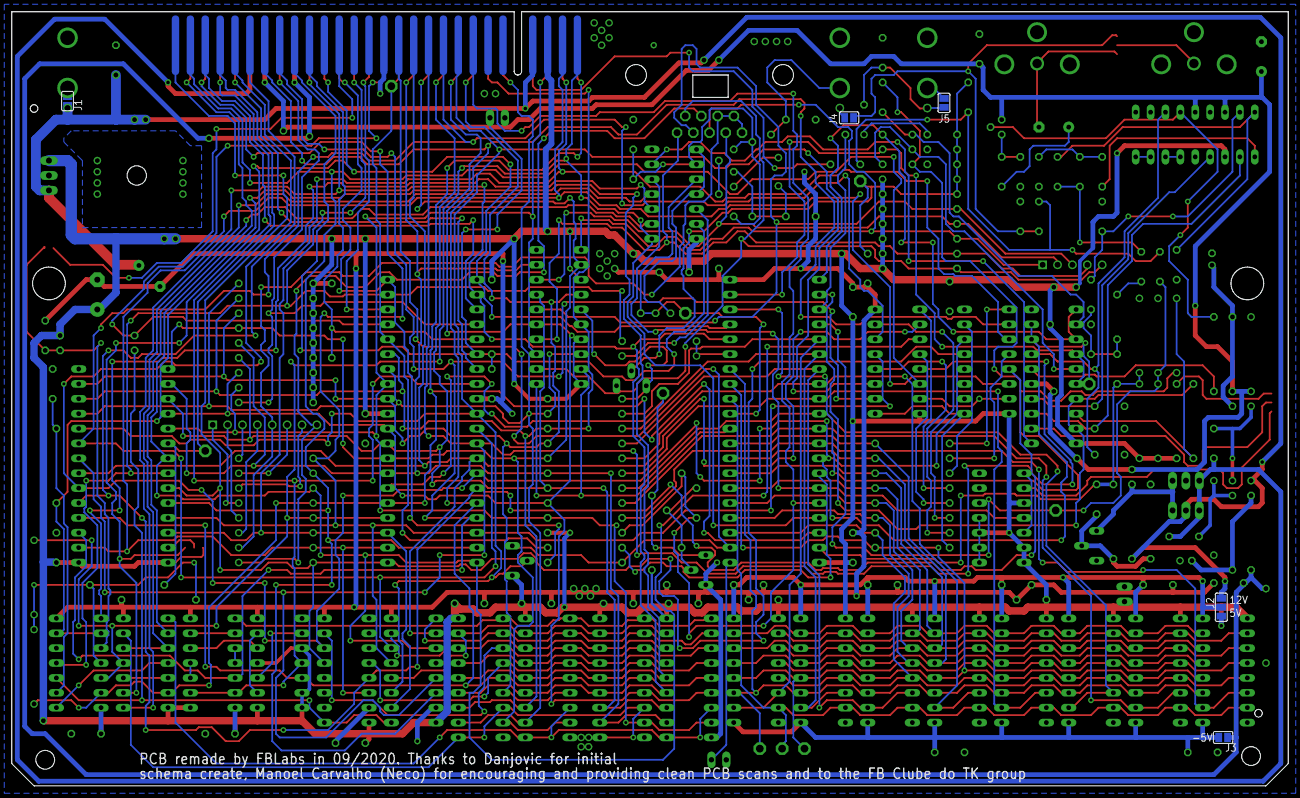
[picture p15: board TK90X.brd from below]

Board: 2 copper layers, 217.8 x 132.1 mm, 224 parts (5 on the bottom side), 179 nets.

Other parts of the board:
U$2: LOGO_FABIO_SILK_400MIL

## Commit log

2020-09-29 Upload inicial, placa pronta, necessário testes
    [TK90X.brd, TK90X.sch]
2020-10-01 Adicionado mod1 com jumpers para selecionar tensões nas DRAMs 4116
    [TK90X.brd, TK90X.sch]
2020-10-02 Mod2 com saída CVBS e áudio no conector estéreo do MIC
    [TK90X.brd, TK90X.sch]
2020-10-02 Alguns ajustes no mod2
    [TK90X.GBL, TK90X.GBO, TK90X.GBS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]
2020-10-04 Organizado pastas. Rev5 terminado
    [TK90X.GBL, TK90X.GBO, TK90X.GBS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]
2020-10-08 Corrigido conexões power Adicionado jumpers de solda pros jacks de áudio Adicionado revisão 6 com 74LS365 substituido pelo 74LS244
    [TK90X.GBL, TK90X.GBO, TK90X.GBS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]
2020-11-05 Corrigido BOMs Adicionado revisão 7 com mais configurações e opções
    [BOM.xlsx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]
2021-01-02 Adicionado BOM e instruções para a revisão 6
    [BOM.xlsx]
2021-01-03 Corrigido valor de R49 e outros pequenos detalhes
    [BOM.xlsx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]
2021-02-13 Pequenas correções
    [BOM.xlsx, TK90X.brd, TK90X.sch]
2021-04-27 Corrigindo footprint dos jacks RCA Corrigindo lista de peças da revisão 7
    [BOM.xlsx, TK90X.brd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]
2021-04-28 Adicionado fotos da placa Rev 7 montada Alterado instruções para formato Markdown Corrigido capacitor C1 na placa rev. 7 Outras pequenas melhorias e correções
    [BOM.xlsx, TK90X.brd, TK90X.sch]
2021-04-29 Adicionado soquetes na lista de material versão em excel. Refeito gerbers e mapa da revisão 7
    [BOM.xlsx, TK90X.brd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]
2021-05-01 Corrigindo posição do conector RCA extra da Rev. 7 Adicionado conteúdo da EPROM Modificado lista de material de Excel para formato Markdown Melhorado documentações
    [BOM.xlsx, TK90X.brd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]
2021-05-23 Corrigido valores de R68 e C52 para melhor geração dos 12V para o Vídeo e DRAMs. Corrigido largura de algumas trilhas
    [TK90X.brd, TK90X.sch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]
2024-02-20 Adicionado Interactive BOM para a Revisão 7
    [TK90X.brd, TK90X.sch]
2024-02-21 Adicionado link para Github pages
